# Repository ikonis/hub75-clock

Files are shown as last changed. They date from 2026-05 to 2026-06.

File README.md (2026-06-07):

# HUB75 Smart Clock

I built this as a bedside clock and it got out of hand. It's a 64×32 HUB75 LED matrix running on a Raspberry Pi 4, showing the time and animated weather conditions pulled from Home Assistant. The LD2410C mmWave sensor handles presence detection, a VEML7700 reads ambient light, and a PIR catches motion. Everything talks to HA over MQTT and shows up as a native device with auto-discovered entities.
Configuration is all YAML. Fonts, colors, brightness curves, which sensors are connected.

Parts of this codebase were written with AI assistance. I have tested it on my own hardware but please audit the code before running it on yours.

---

## Hardware

| Component | Notes |
|---|---|
| [Raspberry Pi 4 Model B](https://amzn.to/4nli8DE) | Debian Bookworm (Raspberry Pi OS Lite), primary supported hardware |
| [64×32 HUB75 LED panel](https://amzn.to/4tELsqA) | P2.5 used in this build. P2/P3/P4/P5 all work electrically; smaller pitch looks better up close |
| [VEML7700](https://amzn.to/3R5NwKr) | Ambient lux, I²C |
| [HLK-LD2410C](https://amzn.to/3Rz9upi) | mmWave presence + distance, UART |
| [PIR sensor (Inland PIR Motion Sensor Module)](https://www.microcenter.com/product/618776/inland-pir-motion-sensor-module) | Motion, GPIO, no adjustment pots, 3-pin VCC/GND/OUT |
| [5V / 5A power supply](https://amzn.to/4drKXKq) | Barrel jack, powers panel + Pi + sensors |

---

## Case / Enclosure

STL and STEP files are in the `case/` folder, designed for the hardware listed in the BOM above. A Bambu Studio `.3mf` file with the print settings used on a P1S is included.

### Variants

**Front cover**
- With cutouts for all three sensors (VEML7700 lux window, PIR dome, LD2410C lens)
- Without VEML7700 cutout, for builds that omit the lux sensor

**Back cover**
- Barrel jack only
- Pi 4 variant with and full port rear cutouts.

**Bottom cover**
- Pi 4
- Pi Zero W

### Hardware required

| Qty | Part | Notes |
|-----|---|---|
| 10 | [M3×5×4 Heatset Inserts](https://amzn.to/3RABtF4) | Panel and cover mounting |
| 6 | [M3×6 Countersunk Screws](https://amzn.to/4wqe6Or) | Front cover to frame |
| 6 | [M3×6 Hex Screws](https://amzn.to/3R4CC7Q) | Back cover to frame |
| 4 | [M2.5×3.5×4 Heatset Inserts](https://amzn.to/3RABtF4) | Pi mounting |
| 4 | [M2.5×5 Hex Screws](https://amzn.to/4u9nSTS) | Pi to standoffs |

---

## Wiring

### Power

```
5V/5A Supply (+) -----> Panel 5V
5V/5A Supply (+) -----> Pi VBUS (physical pin 2)
5V/5A Supply (+) -----> LD2410C VCC
5V/5A Supply (+) -----> PIR VCC
5V/5A Supply (-) -----> Shared GND (all devices)
```

Internal to the enclosure: barrel jack in, split to panel and Pi. One cable in, everything powered.

### VEML7700, I2C, 3.3V

```
VEML7700    Pi 4                Physical pin
VIN    -->  3.3V                1
GND    -->  GND                 9
SDA    -->  GPIO2 (SDA1)        3
SCL    -->  GPIO3 (SCL1)        5
```

Verify after boot: `sudo i2cdetect -y 1`. Expect `0x10`.

### HLK-LD2410C, UART, 5V power

```
LD2410C     Pi 4                Physical pin
VCC    -->  5V                  2
GND    -->  GND                 20
TX     -->  GPIO15 (RXD0)       10   ← CROSSED: sensor TX to Pi RX
RX     -->  GPIO14 (TXD0)       8    ← CROSSED: sensor RX to Pi TX
OUT         (leave unconnected)
```

After install + reboot: `ls -l /dev/ttyAMA0` must exist and `/dev/serial0` must point to it, not `ttyS0`. If it shows `ttyS0` the Bluetooth disable didn't take. Check `/boot/firmware/config.txt` for `dtoverlay=disable-bt`.

### PIR, GPIO

| PIR Pin | Pi BCM GPIO | Pi Physical Pin |
|---|---|---|
| VCC | 3.3V or 5V | Pin 1 or Pin 2 |
| GND | GND | Pin 39 |
| OUT | GPIO16 | Pin 36 |

> GPIO16 is free in the regular hardware mapping. OE uses GPIO18, not GPIO16.

> The Inland PIR sensor works on 3.3V, freeing up the 5V pins for panel power. If powering the Pi from a barrel jack via GPIO rather than USB-C, connect PIR VCC to pin 1 (3.3V) instead.

Change GPIO pin in `config.yaml` under `sensors.pir_gpio` (BCM number, not physical pin). Allow 30–60 seconds warmup after power-on.

### HUB75 Panel

Connect directly via GPIO, no HAT required. Panel power comes from the external supply directly, not through the Pi's 5V rail.

| HUB75 Signal | HUB75 IDC Pin | Pi BCM GPIO | Pi Physical Pin |
|---|---|---|---|
| R1 | 1 | GPIO11 | 23 |
| G1 | 2 | GPIO27 | 13 |
| B1 | 3 | GPIO7 | 26 |
| GND | 4 | GND | 6 |
| R2 | 5 | GPIO8 | 24 |
| G2 | 6 | GPIO9 | 21 |
| B2 | 7 | GPIO10 | 19 |
| GND | 8 | GND | 14 |
| A | 9 | GPIO22 | 15 |
| B | 10 | GPIO23 | 16 |
| C | 11 | GPIO24 | 18 |
| D | 12 | GPIO25 | 22 |
| CLK | 13 | GPIO17 | 11 |
| STB/LAT | 14 | GPIO4 | 7 |
| OE | 15 | GPIO18 | 12 |
| GND | 16 | GND | 25 |

> **Note:** This is the `regular` hardware mapping from rpi-rgb-led-matrix. Your HUB75 panel connector pin numbering may differ. Verify against your panel's datasheet. Pin 1 is usually marked on the connector.

> Pin 1 on the IDC connector is usually marked with a triangle or dot on the PCB silkscreen, or a red stripe on the ribbon cable.

**Note on 3.3V logic:** The Pi's GPIO is 3.3V. HUB75 panels expect 5V logic. Most panels tolerate 3.3V and work fine. If you get garbled output that `gpio_slowdown` tuning doesn't fix, a 74HCT245 buffer between Pi and panel will resolve it.

Use `hardware_mapping: regular` for direct GPIO wiring. Only use `adafruit-hat` if you have an actual Adafruit RGB Matrix Bonnet.

---

## Installation

> **Note:** Git may not be installed on a fresh Raspberry Pi OS image. Install it first:
> ```bash
> sudo apt install -y git
> ```

### 1. Clone the repo on the Pi

```bash
cd ~
git clone https://github.com/YOUR_GITHUB_USER/hub75-clock.git
cd hub75-clock
```

### 2. Install

```bash
bash install.sh
```

`install.sh` handles everything in one step, asks which runtime to install, then launches the interactive configuration wizard (`scripts/configure.sh`) and prompts to reboot. The Python runtime is the stable/public path. The C++ runtime is available as **experimental** for lower overhead, but fresh installs still need more testing.

### 3. Reboot

Prompted automatically by `install.sh`. Required for UART, Bluetooth, and group changes to take effect.

```bash
sudo reboot
```

### 4. Test sensors

```bash
make test
```

Runs each enabled sensor in sequence with a timed window and prints a PASS/FAIL/SKIP summary. Takes ~25 seconds total. Wave your hand in front of the PIR during the last 15 seconds.

```bash
sudo i2cdetect -y 1        # VEML7700 at 0x10
ls -l /dev/serial0         # must point to ttyAMA0
```

### 5. Test the clock

Python runtime:

```bash
sudo python3 /opt/hub75-clock/hub75_clock.py
```

C++ runtime:

```bash
sudo /opt/hub75-clock/hub75_clock /etc/hub75-clock/config.yaml
```

Root required for matrix DMA/PWM. Panel should light up with time. Banner shows `--/-- CLEAR` until HA pushes weather. The C++ runtime is **experimental** and may require dependency/build troubleshooting on fresh installs.

### 6. Start the service

The service is installed and enabled automatically by `install.sh`.

```bash
make start
make status
```

---

## Scripts

### install.sh

Run once on a fresh Pi. Does everything in sequence:

1. Updates apt package lists
2. Installs common system packages, then installs C++ build dependencies only when the C++ runtime is selected
3. Installs Python packages (paho-mqtt, PyYAML, pyserial, RPi.GPIO, adafruit-circuitpython-veml7700, adafruit-blinka, watchdog)
4. Lets you choose the clock runtime:
   - Python Clock: stable path, fast updates, no clock compile required
   - C++ Clock **[EXPERIMENTAL]**: lower overhead, smoother on constrained hardware, compiles during install/update
5. Lets you choose the theme builder mode: off, Home Assistant controlled, or always running
6. Builds and installs `rpi-rgb-led-matrix` with Python bindings. Pi 4: installs a pinned commit via pip. Pi Zero W: clones, checks out commit `076c54b`, and builds with `make build-python` / `make install-python`. The C++ runtime also builds the matrix C++ library. See `docs/pi-zero-w.md`.
7. Downloads fonts (rpi-rgb-led-matrix bundled BDF fonts + Spleen 12x24/16x32) to `~/hub75-fonts`
8. Enables I2C and UART hardware; disables serial console; disables Bluetooth; blacklists `snd_bcm2835`
9. Adds user to `dialout`, `gpio`, `i2c` groups
10. Installs the selected runtime to `/opt/hub75-clock/`; copies built-in themes to `/etc/hub75-clock/themes/` on first install only; update scripts preserve locally edited themes before syncing; copies Python animation `.py` files when using the Python runtime; installs the theme builder helper files
11. Installs and enables the `hub75-clock` systemd service for the selected runtime
12. Installs the `hub75-theme-builder` systemd service, enabled only when theme builder mode is `always`
13. Installs the matching update script to `~/update-clock.sh`
14. Launches `scripts/configure.sh` to write your `config.yaml`
15. Prompts to reboot

```bash
bash install.sh
```

### update scripts

Pulls the latest code from GitHub, copies updated files to `/opt/hub75-clock/`, and restarts the service. `install.sh` installs either `scripts/update-clock-python.sh` or `scripts/update-clock-cpp.sh` as `~/update-clock.sh`, matching the runtime you selected.

```bash
make update
# or: ~/update-clock.sh
```

For C++ clocks, `make update` rebuilds the C++ binary after syncing themes, sprites, and sprite-animation JSON. Normal theme/sprite JSON edits do not require a rebuild by themselves; the C++ clock reloads theme JSON changes while running. New C++ animation code or changes under `clock-cpp/src/animations/` require `make update`. Treat this runtime as **experimental** until the install path has been tested on more fresh Pi images.

The C++ updater checks for build dependencies before compiling. If a migrated clock is missing them, install:

```bash
sudo apt install -y cmake build-essential pkg-config libmosquitto-dev libyaml-cpp-dev libgpiod-dev
```

It also expects the RGB matrix source and C++ library at `~/rpi-rgb-led-matrix`:

```bash
cd ~
git clone https://github.com/hzeller/rpi-rgb-led-matrix.git
cd rpi-rgb-led-matrix
make
```

### switching runtimes

The installed runtime is controlled by the `hub75-clock` systemd service and the updater copied to `~/update-clock.sh`.

To switch from Python to C++ **[EXPERIMENTAL]**:

```bash
cp ~/hub75-clock/scripts/update-clock-cpp.sh ~/update-clock.sh
chmod +x ~/update-clock.sh
make update
sudo systemctl edit --full hub75-clock
```

Set `ExecStart` to:

```ini
ExecStart=/opt/hub75-clock/hub75_clock /etc/hub75-clock/config.yaml
```

Then:

```bash
sudo systemctl daemon-reload
sudo systemctl restart hub75-clock
```

To roll back to Python:

```bash
cp ~/hub75-clock/scripts/update-clock-python.sh ~/update-clock.sh
chmod +x ~/update-clock.sh
make update
sudo systemctl edit --full hub75-clock
```

Set `ExecStart` to:

```ini
ExecStart=/usr/bin/python3 /opt/hub75-clock/hub75_clock.py
```

Then reload and restart systemd again.

### scripts/configure.sh

Interactive configuration wizard. Prompts for your MQTT broker, device name, sensor hardware, GPIO pin, and `gpio_slowdown`, then writes `/etc/hub75-clock/config.yaml` automatically. Launched by `install.sh` on first install; can be re-run any time.

```bash
make config
# or: bash scripts/configure.sh
```

### clock/test_sensors.py

Tests each connected sensor independently without starting the full clock. Reads enabled flags from `config.yaml`, skips disabled sensors, and prints a PASS/FAIL/SKIP summary. Takes ~25 seconds total.

```bash
make test
```

---

## Daily Workflow

```bash
make update     # git pull + copy files + restart service
make logs       # tail live service logs
make restart    # restart after config edit
make status     # check service status
make stop       # stop the service
make start      # start the service
make test       # run test_sensors.py
make config     # open config wizard (reconfigure)
make rgb        # run test_display.py (panel pixel test)
make theme-builder # edit repo themes in the browser
make sprite-builder # edit sprite JSON files in the browser
make ld2410-tuner # tune LD2410 gate thresholds from a phone-friendly page
```

After editing `/etc/hub75-clock/config.yaml` directly:
```bash
make restart
```

---

## Theme Builder

The offline builder is `tools/theme-builder.html`. To edit theme JSON files directly through the browser, run the tiny local helper server:

```bash
make theme-builder
# open http://127.0.0.1:8765/
```

By default it reads and saves themes in the repo `themes/` directory. To edit the installed themes on a clock:

```bash
sudo python3 tools/theme-server.py --themes-dir /etc/hub75-clock/themes --host 0.0.0.0
```

Then browse to `http://<clock-ip>:8765/`. Only run it on a trusted network.

During install, the theme builder can be disabled, left always running, or controlled from Home Assistant. In HA-controlled mode, the clock publishes a Theme Builder switch and a Theme Builder URL sensor through MQTT discovery. The switch starts/stops the `hub75-theme-builder` service; the URL sensor gives you the browser address.

---

## LD2410 Tuner

The LD2410 tuner is a tiny mobile-friendly web UI for live gate tuning:

```bash
make ld2410-tuner
# open http://<clock-ip>:8766/
```

It uses MQTT instead of opening the UART directly, so the clock can keep running while the tuner turns engineering mode on, reads the sensor's saved thresholds, graphs live move/still gate energy, and publishes gate threshold changes through the same commands the clock already understands. Set `ld2410_tuner.mode` to `ha` to expose an HA switch and URL sensor, or `always` to keep the tuner service running.

Distances in the tuner are shown in feet. The LD2410 stores normal gate sensitivity after successful configuration commands. The next tuning layer can expose max-distance, timeout, and distance-resolution controls; distance resolution requires a module restart before it truly takes effect.

---

## Sprite Builder

The sprite builder edits small JSON sprites used by the generic `sprite` cameo in both runtimes:

```bash
make sprite-builder
# open http://127.0.0.1:8765/sprite-builder.html
```

Sprites live in `sprites/` in the repo and `/etc/hub75-clock/sprites/` on clocks. The same page also includes early animation scaffolding for frame-based sprite animation JSON in `sprite-animations/` and `/etc/hub75-clock/sprite-animations/`.

Use sprites from a theme cameo like:

```json
{ "name": "sprite", "sprite": "rocket", "chance_per_minute": 4 }
```

Sprite pixels use `null` for transparent cells, `#RRGGBB` for solid color, or `#RRGGBBAA` for alpha-blended pixels. Sprite JSON can also carry early `movement` metadata for future cameo behavior work. The sprite animation and cameo designer UI is scaffold/experimental design tooling; generated movement JSON is not yet a complete public runtime system.

---

## Updating

Pull the latest code from GitHub and restart the service:

```bash
make update
# or: ~/update-clock.sh
```

This pulls from the current branch, copies the updated files to `/opt/hub75-clock/`, and restarts the service. On the C++ runtime it also rebuilds the binary; on Python it copies the `.py` files directly.

---

## Font Selection

Two fonts configured separately: banner (small text row) and time (large digits).

### Banner font

`4x6.bdf` (default): "TSTORM" plus two temps fits in 64px.

### Time font options

| Font | W×H | "12:34" px wide | Source | Notes |
|---|---|---|---|---|
| `9x15B.bdf` | 9×15 | 45px | rpi-rgb-led-matrix | Smaller bold |
| `9x18B.bdf` | 9×18 | 45px | rpi-rgb-led-matrix | Taller bold |
| `10x20.bdf` | 10×20 | 50px | rpi-rgb-led-matrix | Good default |
| `spleen-12x24.bdf` | 12×24 | 60px | install.sh | Chunky terminal. Recommended upgrade. |
| `spleen-16x32.bdf` | 16×32 | 80px | install.sh | Extreme chonk. Single-digit hours only ("6:15"=48px ✓, "12:34"=80px ✗) |

To change the time font, edit `/etc/hub75-clock/config.yaml`:

```yaml
fonts:
  time_name: spleen-12x24.bdf
  time_w: 12
  time_h: 24
```

**Always update `time_w` and `time_h`. They are not auto-detected.**

Browse available fonts:
```bash
ls ~/rpi-rgb-led-matrix/fonts/
```

Test a font on the real panel:
```bash
cd ~/rpi-rgb-led-matrix/examples-api-use
sudo ./text-example -f ~/rpi-rgb-led-matrix/fonts/spleen-12x24.bdf
```

---

## Home Assistant Setup

### Optional Home Assistant Automation Examples

The clock does not require my Home Assistant helpers, room names, weather entities, or automation structure. It only needs MQTT. You can publish to the topics in `config.yaml` from HA, Node-RED, a shell script, or nothing at all. Without weather MQTT, the clock still runs and shows placeholder banner values until something publishes weather.

The files in `automations/` are optional examples. Copy them only if you want a starting point, then replace the placeholder entity IDs (`YOUR_CLOCK_CLIENT_ID`, `weather.YOUR_WEATHER_ENTITY`, etc.) with your own.

```text
config/
|-- packages/
|   `-- hub75_clock/
|       |-- 01_set_theme.yaml            optional: brightness + calls theme script
|       |-- 01b_select_theme_script.yaml SCRIPT (see note below)
|       |-- 02_push_weather.yaml         optional: weather push every 15 min
|       |-- 03_alerts.yaml               optional: NWS weather alert banner
|       `-- 04_online_offline.yaml       optional: offline notification
`-- scripts/
    `-- clocks_select_theme.yaml         copy of 01b content under script: key
```

In `configuration.yaml`:

```yaml
homeassistant:
  packages: !include_dir_named packages

script: !include_dir_merge_named scripts
```

**Important:** `01b_select_theme_script.yaml` is a script, not an automation. It defines `script.clocks_select_theme`, which the optional `01_set_theme.yaml` automation calls. Scripts and automations use different HA keys and cannot live in the same file. Copy the contents of `01b_select_theme_script.yaml` into your `config/scripts/` directory, or inline it under a `script:` key in a package.

Optional helpers used by the examples:

| Helper | Type | Used for |
|---|---|---|
| `input_select.clock_daypart` | Select | Optional day/night/Away theme selection. Suggested values: Day, Early Morning, Evening, Late Evening, Night, Away. |
| `input_text.clock_condition` | Text | Optional weather condition cache. Written by `02_push_weather`, read by `01b_select_theme_script`. |

Optional entities used by the examples:

| Entity | Source |
|---|---|
| `weather.YOUR_WEATHER_ENTITY` | Any HA weather integration |
| `sensor.YOUR_OUTDOOR_TEMP` | Optional outdoor/current temperature sensor |
| `number.YOUR_CLOCK_CLIENT_ID_brightness` | Auto-discovered brightness control |
| `binary_sensor.YOUR_CLOCK_CLIENT_ID_online` | Auto-discovered availability sensor |

These names are examples, not requirements. If you already have different helpers or entities, map them in the automation YAML or publish directly to MQTT.

### Auto-registered entities (MQTT Discovery)

The clock registers its device and all entities automatically via MQTT Discovery on connect. The device name and entity prefix come from `mqtt.client_id` and `ha_discovery.ha_discovery_name` in `config.yaml`.

With defaults (`client_id: hub75_clock`, `ha_discovery_name: "HUB75 Clock"`):

| Entity | Description |
|---|---|
| `sensor.hub75_clock_illuminance` | VEML7700 lux |
| `sensor.hub75_clock_move_distance` | LD2410C move distance (cm) |
| `sensor.hub75_clock_still_distance` | LD2410C still distance (cm) |
| `binary_sensor.hub75_clock_pir` | PIR motion (shown as "Motion" in HA) |
| `binary_sensor.hub75_clock_presence` | LD2410C occupancy |
| `number.hub75_clock_brightness` | Brightness control (1–100) |

Sensors for disabled hardware (e.g. `veml7700_enabled: false`) are not registered. LD2410 gate energy, gate thresholds, and engineering mode are intentionally kept out of Home Assistant; use the LD2410 tuner web UI or RadarTools for tuning.

### MQTT Topics

**HA → Clock:**

| Topic | Payload |
|---|---|
| `clock/weather` | `{"low_temp": 68, "high_temp": 88, "condition": "TSTORM", "outdoor_temp": 64}` |
| `clock/config` | `{"brightness": 40}` — brightness; additional config keys documented in `config.example.yaml` |
| `{client_id}/theme/set` | Theme name string, e.g. `"Rainy Night"` — per-clock, uses `mqtt.client_id` from config |
| `clock/alert` | `{"message": "Tornado Warning - County - until 4:45 PM", "expires": "2026-04-25T16:45:00-05:00"}` |
| `clock/alert` | `{"clear": true}` to dismiss |

Minimal generic HA service calls:

```yaml
# Set one clock's theme manually.
action: mqtt.publish
data:
  topic: hub75_clock/theme/set
  payload: "Night - Clear"
```

```yaml
# Publish weather/banner data.
action: mqtt.publish
data:
  topic: clock/weather
  retain: true
  payload: '{"low_temp": 68, "high_temp": 88, "condition": "CLEAR", "outdoor_temp": 72}'
```

```yaml
# Publish brightness. If several clocks share clock/config, they all change.
action: mqtt.publish
data:
  topic: clock/config
  payload: '{"brightness": 40}'
```

```yaml
# Optional day/night theme selection idea.
action: mqtt.publish
data:
  topic: hub75_clock/theme/set
  payload: >
    {% if is_state('sun.sun', 'below_horizon') %}
      Night - Clear
    {% else %}
      Day - Clear
    {% endif %}
```

**Clock → HA:**

| Topic | Payload |
|---|---|
| `hub75_clock/lux` | `{"lux": 125.5}` |
| `hub75_clock/pir` | `{"motion": true}` |
| `hub75_clock/presence` | `{"presence": true, "target_state": 3, "move_distance": 85, "still_distance": 120}` |
| `hub75_clock/motion` | `{"move_energy": 45, "still_energy": 30}` |
| `hub75_clock/status` | `online` or `offline` |

### Weather Conditions

If you publish weather data, the clock expects a condition string. The optional example script `clocks_select_theme` maps condition + daypart to a matching theme name, but you can use any mapping you like or select themes manually.

| Condition | Day-side theme | Night-side theme |
|---|---|---|
| `CLEAR` / `SUNNY` / `PARTLYCLOUDY` | Day / Sunrise / Sunset | Night / Late Evening |
| `CLOUDY` / `FOG` / `SMOKE` / `DUST` / `WINDY` | Day (overcast sky) | Night (no stars) |
| `RAIN` / `FLOOD` | Rainy Day | Rainy Night |
| `TSTORM` / `HURRICANE` / `TROPICAL_STORM` | Stormy Day | Stormy Night |
| `SNOW` / `BLIZZARD` | Snowy Day | Snowy Night |
| `SLEET` / `ICE` / `FREEZING_DRIZZLE` / `FREEZING_RAIN` | Sleety Day | Rainy Night |

All precipitation (rain drops, snow flakes, sleet, lightning) is rendered by the `clouds.py` animation via the `precipitation` field in the theme JSON. See `docs/themes.md` for the full field reference.

In the included `02_push_weather.yaml` example, condition is the most severe expected in the next 12 hours, not just the current moment.

The condition and temperature windows are configurable at the top of `automations/02_push_weather.yaml`. Change `condition_hours` (default 12) and `temp_hours` (default 24) to suit your preference.

### Brightness

Brightness can be controlled from the auto-discovered HA number entity or by publishing `{"brightness": 40}` to the configured config topic. The included `automations/01_set_theme.yaml` file is only one optional example.

---

## Tornado Warning Alert

When a Tornado Warning is issued, the banner strip shows a red scrolling overlay. Time and animations stay below. Auto-clears on expiration.

### NWS Alerts setup (HACS)

1. HACS → Integrations → ⋮ → Custom Repositories
2. Add: `https://github.com/finity69x2/nws_alerts` → Integration
3. Install "NWS Alerts" → Restart HA
4. Settings → Devices & Services → Add Integration → NWS Alerts
5. Configure with your GPS coordinates or county code

Only Tornado Warnings trigger the clock alert by default.

To manually test the alert:
```bash
mosquitto_pub -h <broker> -u <user> -P <pass> \
  -t clock/alert \
  -m '{"message":"TEST - County - until 11:59 PM"}'
```

Clear it:
```bash
mosquitto_pub -h <broker> -u <user> -P <pass> \
  -t clock/alert -r \
  -m '{"clear": true}'
```

---

## Troubleshooting

**Blank panel:** Check 5V supply. Check ribbon cable orientation (input side of panel only).

**Garbled colors:** Adjust `panel.gpio_slowdown` (Pi 4: start at 4, try 3–5). If still wrong, add a 74HCT245 buffer.

**Flickering:** Increase `gpio_slowdown`. Confirm `lsmod | grep snd_bcm2835` returns nothing. Service must run as root.

**Time wrong size/position:** `fonts.time_w` and `fonts.time_h` must match the font file exactly. Not auto-detected.

**`/dev/serial0` is `ttyS0`:** Bluetooth still owns PL011. Check for `dtoverlay=disable-bt` in `/boot/firmware/config.txt`. Add it and reboot.

**VEML7700 not found:** `sudo i2cdetect -y 1` should show `10`. Check wiring. Set `sensors.veml7700_enabled: false` to disable.

**Weather stuck at `--/-- CLEAR`:** Manually trigger the weather push automation in HA Developer Tools → Automations. Check the automation trace.

**Alert not clearing:** Publish `{"clear": true}` to `clock/alert` from HA Developer Tools → MQTT.

**`mqtt.broker is not set` error on startup:** Add your broker IP to `/etc/hub75-clock/config.yaml` under `mqtt.broker`, or run `make config` to reconfigure.

---

## File Layout

```
hub75-clock/
├── .gitignore
├── Makefile                    make update / logs / restart / test / config / rgb
├── README.md
├── config.example.yaml         Reference config; configure.sh writes the real config
├── install.sh                  One-shot installer, run once on a fresh Pi
├── update.sh                   Installed to ~/update-clock.sh; called by make update
├── scripts/
│   ├── configure.sh            Interactive config wizard; run by install.sh
│   └── test_display.py         Panel pixel test (make rgb)
├── clock/
│   ├── hub75_clock.py          Main application
│   ├── theme_loader.py         Theme dataclass, JSON loader, file watcher
│   └── test_sensors.py         Per-sensor test utility (make test)
├── themes/
│   └── *.json                  Built-in themes; locally edited installed themes are preserved by update scripts
├── animations/
│   └── *.py                    Built-in drop-in animations; copied to /etc/hub75-clock/animations/
│                               Drop your own .py files there to add custom animations at runtime
├── sprites/
│   └── *.json                  Sprite cameo art for the generic sprite animation
└── automations/
    ├── 01_set_theme.yaml            Optional brightness + theme selection example
    ├── 01b_select_theme_script.yaml Optional script: maps daypart + condition to a theme
    ├── 02_push_weather.yaml         Optional forecast weather MQTT example
    ├── 03_alerts.yaml               NWS alert banner (shared clock/alert topic, all clocks receive)
    └── 04_online_offline.yaml       Optional offline notification example
```

Python custom animations can be added at runtime by dropping a `.py` file into `/etc/hub75-clock/animations/`. C++ animation code lives under `clock-cpp/src/animations/` and is compiled during `make update`. Theme JSON, sprite JSON, and sprite-animation JSON edits do not require a C++ recompile. See `docs/animations.md` for the full interface.

---

## Other Hardware

The Pi 4 is the primary tested platform. Other hardware may work with adjustments:

**Raspberry Pi Zero W**: requires additional build steps. See `docs/pi-zero-w.md`.

**Raspberry Pi 3B / 3B+**: should work with `gpio_slowdown: 3` in `config.yaml`. Untested.

**Raspberry Pi 5**: not currently supported.

---

## Compatibility

| Hardware | Status |
|---|---|
| Raspberry Pi 4 Model B | ✅ Primary / tested |
| Raspberry Pi Zero W 1.1 | 🔧 Community-supported; see `docs/pi-zero-w.md` |
| Raspberry Pi 3B / 3B+ | 🔧 Community-supported, untested, `gpio_slowdown: 3` |
| Raspberry Pi 5 | ❌ Not supported |

---

## Support

---

## License

MIT.

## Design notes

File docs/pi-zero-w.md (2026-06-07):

# HUB75 Smart Clock: Raspberry Pi Zero W Build Notes

> **Note:** The Raspberry Pi 4 is the primary supported platform. This document covers the additional steps required to build and run the clock on a Pi Zero W. These steps are community-supported and require more technical comfort.

---

## Why Pi Zero W Needs Extra Steps

The Pi Zero W uses an ARMv6 processor. Recent versions of the `rpi-rgb-led-matrix` library include code for the Raspberry Pi 5's RP1 chip which fails to compile on ARMv6. `install.sh` works around this by pinning to commit `076c54b`, the last version before RP1 support was added, and building with the library's own `make build-python` target instead of pip.

---

## Hardware Differences

| | Pi Zero W | Pi 4 |
|--|--|--|
| Architecture | ARMv6 32-bit | ARMv8 64-bit |
| gpio_slowdown | 2 | 4 |
| UART port | /dev/serial0 | /dev/ttyAMA0 |
| Performance | Slower, some lag on config changes | Fast, very responsive |
| Build process | Requires RP1 stub hack | Standard build |

---

## OS

Use **Raspberry Pi OS Lite (32-bit, Bookworm)**. Do NOT use 64-bit on Pi Zero W. It is not supported on ARMv6.

---

## Building rpi-rgb-led-matrix on Pi Zero W

`install.sh` handles this automatically. It detects Pi Zero W at runtime, then:

1. Clones `rpi-rgb-led-matrix` to `~/rpi-rgb-led-matrix`
2. Checks out commit `076c54b` (last version before Pi 5 RP1 support was added; later commits fail to compile on ARMv6)
3. Builds the C++ library and Python bindings with the repo's own build targets:

```bash
make build-python PYTHON="$(which python3)"
sudo make install-python PYTHON="$(which python3)"
```

Just run `bash install.sh` as normal. No manual source edits are needed.

If a clock is migrated to the C++ runtime after an older Python-only install, make sure the C++ build dependencies are present:

```bash
sudo apt install -y cmake build-essential pkg-config libmosquitto-dev libyaml-cpp-dev libgpiod-dev
```

The C++ updater also expects the RGB matrix source tree and static library at `~/rpi-rgb-led-matrix`. If they are missing:

```bash
cd ~
git clone https://github.com/hzeller/rpi-rgb-led-matrix.git
cd rpi-rgb-led-matrix
make
```

Normal theme JSON edits do not require a C++ recompile. New C++ animation code or edits under `clock-cpp/src/animations/` do require `make update`.

### Verify after install

```bash
python3 -c "from rgbmatrix import RGBMatrix, RGBMatrixOptions, graphics; print('OK')"
```

---

## Config Changes for Pi Zero W

In `/etc/hub75-clock/config.yaml`:

```yaml
panel:
  gpio_slowdown: 2  # Pi Zero W value

sensors:
  ld2410_port: /dev/serial0  # Pi Zero W UART
```

---

## Performance Notes

The Pi Zero W is a single-core ARMv6 at 1GHz. The installer defaults to the C++ runtime on Pi Zero because it has the lowest CPU overhead, but the Python runtime remains available if you want it. Both runtimes now default to 90fps.

Things that can still add load:

- Receiving lots of MQTT messages (gate data, engineering mode)
- Changing weather condition or theme inputs rapidly

For best performance on Zero W:
- Keep `engineering_mode` off unless actively tuning
- Use the C++ runtime if the Python runtime feels sluggish
- Set `sensors.lux_interval: 60` (already default)

---

## UART on Pi Zero W

Enable UART the same way as Pi 4 via `raspi-config`. The port will be `/dev/serial0` which is a symlink to the correct UART device.

If you have Bluetooth issues (Zero W has BT on the main UART), disable it:

```bash
sudo systemctl disable hciuart
```

Add to `/boot/firmware/config.txt`:
```
dtoverlay=disable-bt
enable_uart=1
```

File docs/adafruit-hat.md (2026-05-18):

# HUB75 Smart Clock: Adafruit RGB Matrix HAT

> **Note:** HAT support is untested and community-supported. The primary supported build uses direct GPIO wiring without a HAT. These notes are provided for users who already have an Adafruit HAT and want to try it, but issues specific to the HAT configuration are not actively supported.

Using an Adafruit RGB Matrix HAT simplifies wiring significantly. Just plug the HAT onto the Pi's 40-pin header and connect the HUB75 panel to the HAT's output connector.

---

## Compatible HATs

| HAT | Notes |
|-----|---|
| [Adafruit RGB Matrix HAT + RTC](https://www.adafruit.com/product/2345) | Basic HAT, no PWM mod |
| [Adafruit RGB Matrix Bonnet](https://www.adafruit.com/product/3211) | Smaller form factor, same pinout |

Both include built-in level shifters, so no separate level shifting is needed.

---

## Wiring

Simply:
1. Seat the HAT onto the Pi 40-pin GPIO header
2. Connect the HUB75 panel's data cable to the HAT's HUB75 output connector
3. Connect panel power (5V) to the HAT's power input terminals or directly to the panel

That's it. No individual wire connections needed.

---

## Config Changes

In `/etc/hub75-clock/config.yaml`, change `hardware_mapping`:

**Standard HAT (no PWM mod):**
```yaml
panel:
  hardware_mapping: adafruit-hat
  gpio_slowdown: 4  # Pi 4
```

**HAT with PWM modification (better image quality, less flicker):**
```yaml
panel:
  hardware_mapping: adafruit-hat-pwm
  gpio_slowdown: 4  # Pi 4
```

---

## PWM Modification (Optional but Recommended)

The Adafruit HAT has a solder jumper that enables hardware PWM for smoother display output. See Adafruit's guide:
https://learn.adafruit.com/adafruit-rgb-matrix-plus-real-time-clock-hat-for-raspberry-pi/driving-matrices

If you do the PWM mod, use `adafruit-hat-pwm` as the hardware_mapping.

---

## Sensor Wiring with HAT

The HAT occupies most of the GPIO header but leaves some pins exposed. Check your specific HAT's documentation for which pins are available.

For the LD2410C UART, the HAT typically leaves the UART pins (GPIO14/15, physical pins 8/10) accessible. Connect LD2410C to those.

For the PIR sensor, use a GPIO pin that is not used by the HAT. GPIO26 (physical pin 37) is typically free on Adafruit HATs.

---

## configure.sh

When running `./scripts/configure.sh`, select **Adafruit HAT** or **Adafruit HAT (PWM mod)** when prompted for hardware mapping. The script will set the correct value automatically.

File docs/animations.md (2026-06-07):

# Animations

The C++ runtime uses the same cameo names as the Python runtime, but animation code is compiled from `clock-cpp/src/animations/*.cpp`. Adding or changing C++ animation code requires `make update` on the clock so the binary is rebuilt and reinstalled. Plain theme JSON, sprite JSON, and sprite-animation JSON edits do not require a C++ rebuild.

The Python runtime supports a drop-in animation system. Any `.py` file placed in `/etc/hub75-clock/animations/` is automatically loaded at runtime. The watchdog detects new and changed files within seconds — no restart required.

Animations are triggered as **cameos** inside theme JSON files. See `docs/themes.md` for how to add them to a theme.

---

## How the drop-in system works

1. `AnimationLoader` scans `/etc/hub75-clock/animations/` at startup and imports every `.py` file that contains a class named `Animation`.
2. Each `Animation` class is registered under its `name` attribute.
3. A watchdog monitors the directory. When any `.py` file changes or a new one appears, the loader rescans and rebuilds the registry.
4. The built-in `shooting_star` animation is always registered as a fallback even if the directory is empty.
5. `CameoManager` uses the registry when a theme's `cameos` list asks for an animation by name.

---

## Writing a custom animation

Create a file in `/etc/hub75-clock/animations/` with exactly this structure:

```python
import math
import random

class Animation:
    name = "my_animation"          # unique string key — must match what you put in themes
    conditions = []                # informational: intended weather conditions (not enforced at runtime)
    themes = []                    # informational: intended theme names (not enforced at runtime)
    layer = "foreground"           # "celestial" draws before sun/moon; "foreground" draws last
    persistent = False             # True = runs every frame without a chance_per_minute roll
    speed = 1.0                    # optional multiplier for motion/twinkle speed

    def __init__(self, width, height, cfg, animator):
        self._w = width
        self._at = animator.anim_top   # first row of the animation zone (row 8 on a 64×32 panel)
        self._ab = animator.anim_bottom  # last row of the animation zone (row 31)
        # Initialize your animation state here

    def update(self):
        # Advance state by one frame. Called every frame before draw().
        pass

    def draw(self, canvas):
        # Draw to canvas using canvas.SetPixel(x, y, r, g, b).
        # x must be in 0 .. width-1.
        # y must be in anim_top .. anim_bottom.
        # Do NOT draw outside the animation zone.
        pass

    def is_done(self) -> bool:
        # Return True when the animation has finished. CameoManager will discard it.
        # For persistent animations, return False always.
        return False
```

For Python, drop the file into `/etc/hub75-clock/animations/`. The clock picks it up within a few seconds. Add its `name` to a theme's `cameos` list:

```json
"cameos": [
  {"name": "my_animation", "chance_per_minute": 3}
]
```

---

## Cameo runtime

`CameoManager` maintains one one-shot animation slot plus persistent animations:

- **One-shot slot (`_active`)**: The normal cameo slot. Spawned via `chance_per_minute` probability rolls. Only one runs at a time; while one is active, new rolls are skipped. Cleared on condition change.
- **Persistent animations**: Started once when the theme is applied. They run every frame without any roll and are cleared only on theme change, surviving condition changes. Used for continuously visible effects such as `stars` and `clouds`.

A persistent animation sets `persistent = True` on its class and should return `False` from `is_done()` always. It does not need a `chance_per_minute` entry in the cameos array:

```json
"cameos": [{"name": "stars"}, {"name": "clouds"}]
```

---

## Draw layer ordering

Animations declare their draw layer via the `layer` class attribute:

| Value | When drawn | Examples |
|---|---|---|
| `"celestial"` | After background fill, before sun/moon and clouds | `stars`, `shooting_star`, `meteor`, `comet`, `satellite` |
| `"foreground"` | After clouds, on top of weather particles | `ghost`, `ufo`, all others |

Draw order each frame: background fill -> celestial cameos (`stars`, `shooting_star`, `meteor`, `comet`) -> sun/moon -> clouds and precipitation -> foreground cameos.

---

## Class attributes

### `name` (required)

A unique string key. This is what you put in the theme JSON. If two files declare the same name the second one loaded wins (load order is alphabetical by filename).

### `conditions` (optional, list of strings)

Informational metadata describing the weather conditions this animation is designed for (e.g. `["CLEAR", "RAIN"]`). **Not enforced at runtime.** The clock does not check this attribute before spawning — if the animation is listed in a theme's `cameos` array, it will fire regardless of the current weather condition.

Use this field as documentation for yourself and for tools like the theme builder. An empty list (`[]`) means "suitable for any condition."

### `themes` (optional, list of strings)

Informational metadata describing the theme names this animation is designed for (e.g. `["Night", "Day"]`). **Not enforced at runtime.** The clock does not check this attribute before spawning.

An empty list (`[]`) means "suitable for any theme."

### `layer` (optional, string)

Controls where in the draw stack this animation is rendered. Default is `"foreground"`.

- `"celestial"` — rendered after the background fill and before sun/moon and weather particles. Use for sky objects such as stars, meteors, shooting stars, satellites, and comets.
- `"foreground"` — rendered after clouds and precipitation. Use for everything else.

### `persistent` (optional, bool)

Default `False`. When `True`, the animation is instantiated once when the theme is applied and runs every frame without a `chance_per_minute` roll. It is replaced only when the theme changes. Persistent animations should always return `False` from `is_done()`.

### `speed` (optional, float)

Default `1.0`. Built-in animations use this as a simple multiplier for movement, twinkle, or drift speed so timing can be tuned without rewriting update logic.

Python and C++ load runtime speed settings from `/etc/hub75-clock/animations.yaml` when present. The update scripts install the example file only if it is missing, so local speed tuning survives `make update`.

---

## `__init__` parameters

| Parameter | Type | Description |
|---|---|---|
| `width` | int | Panel width in pixels (64 for a 64×32 panel) |
| `height` | int | Panel height in pixels (32 for a 64×32 panel) |
| `cfg` | dict | The full clock config dict. Access MQTT or other settings if needed. Usually not needed. |
| `animator` | WeatherAnimator | The running animator instance. Use `animator.anim_top` and `animator.anim_bottom` for the animation zone boundaries. |

---

## Drawing API

`canvas.SetPixel(x, y, r, g, b)` — set a single pixel.

- `x`: 0–63 (left to right)
- `y`: 0–31 (top to bottom)
- `r`, `g`, `b`: 0–255

The animation zone runs from `anim_top` (row 8) to `anim_bottom` (row 31). Rows 0–7 are the banner strip (time, temps, condition). Always guard your pixel writes:

```python
if 0 <= px < self._w and self._at <= py <= self._ab:
    canvas.SetPixel(px, py, r, g, b)
```

---

## Minimal working example

A single pixel that blinks yellow and drifts across the screen:

```python
import random

class Animation:
    name = "blink_dot"
    conditions = []
    themes = []

    def __init__(self, width, height, cfg, animator):
        self._w = width
        self._at = animator.anim_top
        self._ab = animator.anim_bottom
        self.x = 0.0
        self.y = float(self._at + random.randint(0, self._ab - self._at))
        self._frame = 0

    def update(self):
        self.x += 0.4
        self._frame += 1

    def draw(self, canvas):
        if self._frame % 8 < 4:   # blink: on for 4 frames, off for 4
            px, py = int(self.x), int(self.y)
            if 0 <= px < self._w and self._at <= py <= self._ab:
                canvas.SetPixel(px, py, 255, 220, 0)

    def is_done(self) -> bool:
        return self.x > self._w + 2
```

---

## Built-in animations reference

Python installs these to `/etc/hub75-clock/animations/`. C++ compiles the matching sources from `clock-cpp/src/animations/` during `make update`.

### Space / Night

Celestial animations are drawn before sun/moon and clouds so meteors appear to fall behind weather. Foreground night animations draw after clouds.

| File | Name | Conditions | Themes | Description |
|---|---|---|---|---|
| `stars.py` | `stars` | CLEAR, PARTLYCLOUDY | Night, Late Evening | **Persistent.** Twinkling star field. Add without `chance_per_minute`; rendered in the celestial layer before sun/moon. |
| `shooting_star.py` | `shooting_star` | CLEAR, PARTLYCLOUDY | Night, Late Evening | Fast diagonal streak with fading tail. Built-in fallback; always registered even if the file is missing. |
| `ufo.py` | `ufo` | CLEAR, PARTLYCLOUDY | Night, Late Evening | Saucer silhouette drifting across with cycling teal belly lights, glow trail, and occasional tractor beam abduction sequence. |
| `satellite.py` | `satellite` | CLEAR | Night | ISS-profile cross sprite, slow diagonal pass from top-right to bottom-left. |
| `meteor.py` | `meteor` | CLEAR | Night, Late Evening | Fast bidirectional diagonal (3.5–5 px/frame) with 6-frame orange/red history trail. |
| `comet.py` | `comet` | CLEAR | Night | Slow diagonal with 10–14px blue-white gradient tail, always drifts downward. |

### Day / Sky (layer: foreground)

| File | Name | Conditions | Themes | Description |
|---|---|---|---|---|
| `clouds.py` | `clouds` | _(any)_ | Day, Sunrise, Sunset, Late Evening | **Persistent.** Drifting clouds plus optional precipitation particles. Count, size, and speed driven by `cloud_density`/`cloud_speed`. Precipitation type set by `precipitation` field (`"none"`, `"rain"`, `"heavy_rain"`, `"tstorm"`, `"snow"`, `"sleet"`). Tstorm mode adds random lightning bolts and background flash. All particles are owned by their parent cloud and wrap with it. |
| `airplane.py` | `airplane` | _(any)_ | Day, Sunrise, Sunset | 8px fuselage + wings + windows, random left/right direction, mirrors sprite to face direction of travel. |
| `sprite.py` / `sprite.cpp` | `sprite` | _(any)_ | _(any)_ | Generic JSON sprite cameo. Loads art from `/etc/hub75-clock/sprites/`; use theme JSON such as `{ "name": "sprite", "sprite": "rocket", "chance_per_minute": 4 }`. |
| `bird_flock.py` | `bird_flock` | _(any)_ | Day | V-formation of 5–7 birds with alternating flap frames. |
| `butterfly.py` | `butterfly` | CLEAR | Day | Open/closed wing frames every 5 ticks, sine wave vertical drift, orange. |
| `flutterflies.py` | `flutterflies` | CLEAR | Day | **Persistent.** Small pastel butterfly group with gentle wandering motion. Add without `chance_per_minute`. |
| `hot_air_balloon.py` | `hot_air_balloon` | CLEAR, PARTLYCLOUDY | Day, Sunrise | 7×10px balloon with ROYGBIV stripes, drifts upward. |
| `tumbleweed.py` | `tumbleweed` | _(any)_ | Day | 5px circle with rotation transform, slight bounce via `|sin|×1.5`. |

### Weather (layer: foreground)

| File | Name | Conditions | Themes | Description |
|---|---|---|---|---|
| `rainbow.py` | `rainbow` | CLEAR, PARTLYCLOUDY | Day | ROYGBIV arc using radius math per band, 2px thick, fade in 15 / hold 45 / fade out 15 frames. |
| `firefly.py` | `firefly` | CLEAR | Night, Late Evening | 6–8 dots with independent sine-phase blink, slow random drift, yellow-green, 2px tall. |
| `snowman.py` | `snowman` | SNOW | _(any)_ | Pixel-art snowman lower-right corner, fade in 20 / hold 90 / fade out 20 frames, flickering eyes. |

### Holiday (layer: foreground)

| File | Name | Conditions | Themes | Description |
|---|---|---|---|---|
| `santa.py` | `santa` | _(any)_ | Night, Late Evening | 14px-wide sleigh + reindeer silhouette, right-to-left, sine wave altitude. |
| `fireworks.py` | `fireworks` | _(any)_ | _(any)_ | 1–3 rockets with staggered launches. Physics-based: gravity applied each frame, apex triggers explosion. 16–20 sparks per burst with velocity-based tails at 60%/30% brightness. |
| `jack_o_lantern.py` | `jack_o_lantern` | _(any)_ | Night, Late Evening | 9×7px orange pumpkin with triangle eyes, triangle nose, zigzag mouth. Lower-right corner, fade in/out. |
| `easter_egg.py` | `easter_egg` | _(any)_ | Day | 6×8px oval with 4-color stripe pattern, bounces left-to-right with slight vertical bob. |

### Fun (layer: foreground)

| File | Name | Conditions | Themes | Description |
|---|---|---|---|---|
| `rocket.py` | `rocket` | _(any)_ | _(any)_ | 3×7px rocket sprite, accelerates upward from a random X position, flame trail below, exits top. |
| `submarine.py` | `submarine` | _(any)_ | Day | Long hull + conning tower + periscope, slow left-to-right with slight sine wave. |
| `ghost.py` | `ghost` | _(any)_ | Night, Late Evening | Pac-Man ghost (7×8px): Blinky/Pinky/Inky/Clyde colors, directional pupils, scalloped bottom, sine float. |

---

## Chance per minute tuning

`chance_per_minute` controls how often a cameo spawns on average. The roll is evaluated every frame:

```
probability_per_frame = chance_per_minute / 60 / fps
```

At 90 fps with `chance_per_minute: 8`:

```
8 / 60 / 90 = 0.0015  →  ~1 spawn per 675 frames (~7.5 seconds)
```

At lower FPS, the per-frame probability is higher so the per-minute rate stays the same:

```
8 / 60 / 30 = 0.0044  →  still ~8 spawns per minute on average
```

Typical values:

| Rate | Feel |
|---|---|
| 1–2 | Rare, occasional surprise |
| 4–8 | Regular — visible but not constant |
| 15–20 | Frequent |
| 30+ | Near-continuous |

Only one cameo runs at a time. While one is active, rolls for all cameos are skipped. High rates shorten the idle time between cameos; a new one starts almost immediately after the previous finishes.

---

## Tips

- **Keep animations entirely within the animation zone.** The banner rows (0–7) must stay intact. Always guard pixel writes with the `anim_top` / `anim_bottom` check.
- **Do not import heavy libraries.** `math` and `random` are always available. Avoid anything that requires install-time dependencies.
- **Name collisions:** if your file's `Animation.name` matches an existing built-in, your file wins because `_scan()` processes files alphabetically and yours will likely run after the built-in. Prefix custom names to avoid accidental overrides (`"my_ufo"` instead of `"ufo"`).
- **Errors are logged, not crashed.** If your file has a syntax error or the `Animation` class is missing required attributes, the loader prints a warning and skips the file. The rest of the animations continue working.
- **Test Python interactively:** run the clock manually (`sudo python3 /opt/hub75-clock/hub75_clock.py`) and watch the logs with `make logs` while you drop files in. The watchdog reloads within 2 seconds of a file write.
- **Test C++ changes:** run `make update` on the C++ clock. The C++ updater syncs themes/sprites first, then rebuilds `clock-cpp` and swaps the installed binary. Plain theme JSON, sprite JSON, and sprite-animation JSON edits do not require a C++ rebuild.

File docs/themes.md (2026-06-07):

# Themes

Themes control the background, text colors, and animation behavior of the clock face. Each theme is a JSON file. The clock loads all `.json` files from its themes directory at startup and watches for changes. Drop a new file in and the clock picks it up within seconds, no restart required.

---

## Where themes live

Built-in themes are installed to `/etc/hub75-clock/themes/` by `install.sh`. That is also where the clock reads them from at runtime. Add your own `.json` files to the same directory.

```
/etc/hub75-clock/themes/
├── Day - Clear.json
├── Day - Rain.json
├── Evening - Clear.json
├── Night - Partly Cloudy.json
├── Away.json
├── Test - shooting_star.json
└── your_custom_theme.json   ← drop it here
```

The repo ships the built-in themes under `themes/` and the installer copies them on first install. `make update` preserves installed themes by copying `/etc/hub75-clock/themes/` back into the repo before syncing, then commits and pushes theme changes by default. Set `PRESERVE_LOCAL_THEMES=false`, `COMMIT_LOCAL_THEMES=false`, or `PUSH_LOCAL_THEMES=false` when running the update script if you want to override that behavior.

---

## Activating a theme

**From Home Assistant:** The clock registers a `select` entity (`Theme`) on the device page. Pick any loaded theme from the dropdown. The selection takes effect immediately.

**Via MQTT:** Publish the theme name as a plain string or as a JSON object to the theme command topic:

```bash
# Plain string
mosquitto_pub -h <broker> -u <user> -P <pass> \
  -t hub75_clock/theme/set \
  -m 'Night'

# JSON object
mosquitto_pub -h <broker> -u <user> -P <pass> \
  -t hub75_clock/theme/set \
  -m '{"theme": "Night"}'
```

The clock publishes the active theme name to `hub75_clock/theme/state` (retained) so the HA select entity stays in sync.

**Available themes list:** `hub75_clock/themes/available` (retained JSON array) is updated automatically whenever files are added or removed from the themes directory.

---

## JSON schema

Every field except `name` is optional. Omitting a field uses the default.

### Identity

| Field | Type | Default | Description |
|---|---|---|---|
| `name` | string | **required** | Display name shown in Home Assistant and used as the theme identifier. Must be unique across all files in the themes folder. |
| `description` | string | `""` | Free-text note for your own reference. Not displayed anywhere by the clock. |

### Background

| Field | Type | Default | Description |
|---|---|---|---|
| `background_type` | string | `"solid"` | `"solid"` fills the animation zone with a single color. `"gradient"` blends between two colors with a split point. |
| `background_color` | hex string | `"#000820"` | Fill color when `background_type` is `"solid"`. |
| `background_top` | hex string | `"#0F0019"` | Top color when `background_type` is `"gradient"`. |
| `background_bottom` | hex string | `"#3C1400"` | Bottom color when `background_type` is `"gradient"`. |
| `background_split` | float 0.0–1.0 | `0.5` | Fraction of the animation zone height where the gradient transitions. `0.5` = halfway. `0.25` = upper quarter. |
| `background_gradient_direction` | string | `"sunset"` | `"sunrise"` or `"sunset"`. Controls which end is solid and which fades. See [Gradient direction](#gradient-direction) below. |

### Text colors

All values are hex color strings (`"#RRGGBB"`). When a key is present in the theme, it overrides the day/night color from `config.yaml` for that element.

| Field | Type | Default | Description |
|---|---|---|---|
| `colors.time` | hex string | from config | Large clock digits. |
| `colors.low_temp` | hex string | from config | Low temperature value in the banner. |
| `colors.high_temp` | hex string | from config | High temperature value in the banner. |
| `colors.condition` | hex string | from config | Weather condition word in the banner (e.g. `RAIN`, `CLEAR`). |

### Cameos

Animations are configured through the `cameos` array. One-shot cameos fire at a configurable rate. Persistent cameos, such as `stars` and `clouds`, start when the theme is applied and run every frame without a rate.

| Field | Type | Default | Description |
|---|---|---|---|
| `cameos` | array | `[]` | List of cameo objects. Each has `name` (string). One-shot cameos also use `chance_per_minute` (float). |

**Cameo object fields:**

| Field | Type | Description |
|---|---|---|
| `name` | string | Which animation to spawn. Python names come from `/etc/hub75-clock/animations/*.py`; C++ names come from compiled animations in `clock-cpp/src/animations/`. |
| `chance_per_minute` | float | Expected spawns per minute on average for one-shot cameos. Omit for persistent animations. |

Example:

```json
"cameos": [
  {"name": "stars"},
  {"name": "shooting_star", "chance_per_minute": 8},
  {"name": "ufo", "chance_per_minute": 2}
]
```

**Built-in animations** (installed to `/etc/hub75-clock/animations/` by `install.sh`):

| Name | Layer | Conditions | Themes | Description |
|---|---|---|---|---|
| `stars` | celestial | CLEAR, PARTLYCLOUDY | Night, Late Evening | **Persistent** - add without `chance_per_minute`. Twinkling star field rendered before the sun/moon layer. |
| `clouds` | foreground | _(any)_ | Day, Sunrise, Sunset, Late Evening | **Persistent** — add without `chance_per_minute`. Handles clouds AND all precipitation (rain, tstorm with lightning, snow, sleet). Driven by `cloud_density`, `cloud_speed`, `precipitation`, and `colors.cloud_day`. |
| `shooting_star` | celestial | CLEAR, PARTLYCLOUDY | Night, Late Evening | Fast diagonal streak with fading tail |
| `ufo` | foreground | CLEAR, PARTLYCLOUDY | Night, Late Evening | Saucer silhouette, cycling belly lights, occasional tractor beam abduction |
| `satellite` | celestial | CLEAR | Night | ISS-silhouette cross, diagonal slow pass |
| `meteor` | celestial | CLEAR | Night, Late Evening | Fast bidirectional diagonal with orange/red history trail |
| `comet` | celestial | CLEAR | Night | Slow diagonal with blue-white gradient tail |
| `airplane` | foreground | _(any)_ | Day, Sunrise, Sunset | Fuselage + wings + windows, mirrors to face direction of travel |
| `bird_flock` | foreground | _(any)_ | Day | V-formation of 5–7 birds with alternating flap frames |
| `butterfly` | foreground | CLEAR | Day | Open/closed wing frames, sine wave vertical drift, orange |
| `flutterflies` | foreground | CLEAR | Day | **Persistent** - add without `chance_per_minute`. Small pastel butterfly group with gentle wandering motion |
| `hot_air_balloon` | foreground | CLEAR, PARTLYCLOUDY | Day, Sunrise | 7×10px balloon with ROYGBIV stripes, drifts upward |
| `tumbleweed` | foreground | _(any)_ | Day | Rolling circle with rotation transform, slight bounce |
| `rainbow` | foreground | CLEAR, PARTLYCLOUDY | Day | ROYGBIV arc, 2px thick bands, fade in/hold/fade out |
| `firefly` | foreground | CLEAR | Night, Late Evening | 6–8 dots, independent sine-phase blink, slow drift, 2px tall |
| `snowman` | foreground | SNOW | _(any)_ | Pixel-art snowman, lower-right corner, fade in/out |
| `santa` | foreground | _(any)_ | Night, Late Evening | Sleigh + reindeer silhouette, right-to-left, sine altitude |
| `fireworks` | foreground | _(any)_ | _(any)_ | 1–3 physics-based rockets, 16–20 sparks each with velocity tails |
| `jack_o_lantern` | foreground | _(any)_ | Night, Late Evening | 9×7px pumpkin with triangle eyes and zigzag mouth, fade in/out |
| `easter_egg` | foreground | _(any)_ | Day | 6×8px striped oval, bounces left-to-right |
| `rocket` | foreground | _(any)_ | _(any)_ | 3×7px rocket, accelerates upward from random X, flame trail |
| `submarine` | foreground | _(any)_ | Day | Long hull + conning tower + periscope, slow left-to-right |
| `ghost` | foreground | _(any)_ | Night, Late Evening | Pac-Man ghost (Blinky/Pinky/Inky/Clyde colors), directional pupils, sine float |

The `layer` column shows when the animation is drawn relative to sun/moon and weather particles. `celestial` renders before sun/moon and clouds; `foreground` renders after clouds. See `docs/animations.md` for details.

See `docs/animations.md` for the drop-in animation interface and how to write your own.

### Clouds and precipitation

All clouds and precipitation are handled by the persistent `clouds` cameo animation. To enable clouds (with or without precipitation), add `{"name": "clouds"}` to the `cameos` array. Cloud count, size, speed, and particle type are controlled by the fields below.

| Field | Type | Default | Description |
|---|---|---|---|
| `cloud_density` | string | `"medium"` | Number of clouds. `"sparse"` = 2, `"medium"` = 4, `"dense"` = 7. |
| `cloud_speed` | string | `"medium"` | How fast clouds drift left. `"slow"` = 0.2 px/frame, `"medium"` = 0.4, `"fast"` = 0.7. |
| `precipitation` | string | `"none"` | Precipitation particles to emit below clouds. See table below. |
| `colors.cloud_day` | hex string | `"#646464"` | Cloud body color. Override per-theme for mood. |

**Precipitation modes:**

| Value | Effect |
|---|---|
| `"none"` | Clouds only, no particles. |
| `"rain"` | 2–4 blue rain streaks per cloud, 1.5 px/frame. |
| `"heavy_rain"` | 4–6 darker streaks per cloud, 2.5 px/frame. |
| `"tstorm"` | Heavy rain plus lightning bolts (8–15 s intervals) with a brief background flash. |
| `"snow"` | 2–3 white dots per cloud, 0.3–0.5 px/frame with gentle lateral wobble. |
| `"sleet"` | Mixed: half fast cyan-gray streaks, half slow wobbling dots. |

All particles are owned by the cloud that spawned them. They fall downward and wrap back to the cloud bottom when they exit the animation zone. When the cloud wraps around to the right edge, its particles are reset.

### Sun and Moon

| Field | Type | Default | Description |
|---|---|---|---|
| `sun_enabled` | bool | `true` | Draw the sun quarter-circle glow in the top-right corner when the condition is SUNNY and night mode is off. Set to `false` for themes where the background already represents the sun (e.g. sunrise gradient, sunset gradient), so the glow doesn't stack on top of the coloured sky. |
| `moon_enabled` | bool | `false` | Draw a small moon disk (radius 3, ~7×7px) in the upper-left corner of the animation zone with a mottled gray surface and a dim glow border. Intended for night and late-evening themes. |

### Condition overrides

| Field | Type | Default | Description |
|---|---|---|---|
| `condition_overrides` | object | `{}` | Per-condition background overrides. Keys are condition strings (see below). Values are objects containing any subset of the background fields (`background_type`, `background_color`, `background_top`, `background_bottom`, `background_split`, `background_gradient_direction`). Text colors, `cameos`, `sun_enabled`, and `moon_enabled` cannot be overridden per-condition. |

Example:

```json
"condition_overrides": {
  "TSTORM": {
    "background_type": "solid",
    "background_color": "#010005"
  },
  "RAIN": {
    "background_type": "gradient",
    "background_top": "#030010",
    "background_bottom": "#010008",
    "background_gradient_direction": "sunset"
  }
}
```

---

## Valid condition strings for overrides

```
CLEAR           SUNNY           PARTLYCLOUDY    CLOUDY
RAIN            SNOW            SLEET           TSTORM
ICE             FLOOD           BLIZZARD        HURRICANE
TROPICAL_STORM  FREEZING_RAIN   FREEZING_DRIZZLE
DUST            SMOKE
```

Aliased conditions (BLIZZARD→SNOW, HURRICANE→TSTORM, FLOOD→RAIN, etc.) are normalized before the override lookup, so use the canonical name, not the alias, as the key.

---

## Gradient direction

`background_gradient_direction` controls which portion of the animation zone is a solid fill and which fades.

```
sunrise:                    sunset:
┌──────────────┐            ┌──────────────┐
│  background  │            │  background  │  ← solid top
│     _top_    │  ← fades   │     _top_    │
│              │    down     │              │
├──────────────┤            ├──────────────┤  ← split point
│              │            │              │
│  background  │  ← solid   │  background  │  ← fades down
│   _bottom_   │   bottom   │   _bottom_   │
└──────────────┘            └──────────────┘
```

**Sunrise:** The top portion fades from `background_top` (at the very top) down to `background_bottom` (at the split). The bottom portion below the split is a solid fill of `background_bottom`. Good for dawn: dark purple sky above a warm horizon, flat dark ground below.

**Sunset:** The top portion above the split is a solid fill of `background_top`. The bottom portion fades from `background_top` (at the split) down to `background_bottom` (at the very bottom). Good for dusk. The sky holds its color and bleeds into a warm horizon at the bottom.

`background_split: 0.5` puts the transition at the vertical midpoint of the animation zone. Lower values (e.g. `0.25`) push it toward the top; higher values (e.g. `0.75`) push it toward the bottom.

---

## Installing a theme

1. Write your JSON file (see [example](#complete-example) below).
2. Copy it to the themes directory:
   ```bash
   sudo cp stormy_night.json /etc/hub75-clock/themes/
   ```
3. The clock detects the new file within a few seconds and adds it to the available themes list.
4. Select it from the HA device page or via MQTT.

No restart or C++ recompile is required for normal theme JSON edits. New C++ animation code or changes to compiled animation behavior still require `make update` on the C++ clock.

---

## Complete example

`stormy_night.json`: a dark, dramatic theme for thunderstorm nights with lightning.

```json
{
  "name": "Stormy Night",
  "description": "Dark stormy sky with lightning",

  "background_type": "solid",
  "background_color": "#010004",

  "colors": {
    "time":      "#383838",
    "low_temp":  "#001C2A",
    "high_temp": "#2A1100",
    "condition": "#141418",
    "cloud_day": "#1C1C24"
  },

  "cameos": [{"name": "clouds"}],

  "cloud_density": "dense",
  "cloud_speed": "fast",
  "precipitation": "tstorm",

  "sun_enabled": false,
  "moon_enabled": false
}
```

**Field-by-field notes:**

- `background_color: "#010004"`: near-black with a faint purple tint. Keeps the panel very dim.
- `colors.time: "#383838"`: dark grey — a bright clock face is intrusive at night.
- `colors.cloud_day: "#1C1C24"`: very dark clouds, barely visible — storm clouds blocking all light.
- `precipitation: "tstorm"`: heavy rain particles plus random lightning bolts with a brief background flash. Lightning interval is 8–15 seconds.
- `cloud_density: "dense"` + `cloud_speed: "fast"`: 7 fast-moving clouds feel stormy and oppressive.
- No `stars` cameo: no stars; total overcast.

---

## Tips

- **Keep colors dim for night themes.** Time and temperature colors in the `#303030`–`#606060` range are readable without lighting up a dark room. Use `#F0F0F0` only for daytime themes.

- **Condition overrides are the right place for weather-reactive backgrounds.** A day theme might have a bright blue sky by default but darken to near-black during TSTORM. That way you get one theme that adapts rather than needing separate themes for every combination of time-of-day and weather.

- **Theme names must be unique** across all `.json` files in the themes folder. If two files declare the same `name`, the second one loaded wins (load order is filesystem-alphabetical). Use a clear, descriptive name.

- **You can have as many themes as you want.** The HA select entity updates its options list automatically. There is no limit.

- **Drop a theme file in place to update it.** The watchdog detects the write and reloads. If the active theme was modified, it stays active with the new settings applied immediately.

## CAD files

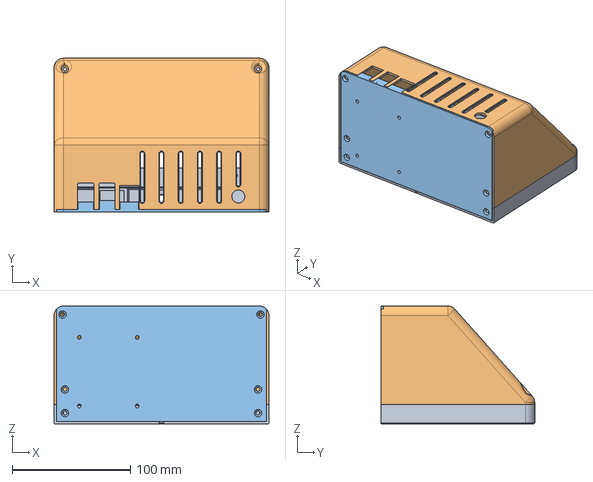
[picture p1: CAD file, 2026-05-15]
case/step files/Whole Assembly (pi4).step
181.9 x 129.9 x 99.8 mm

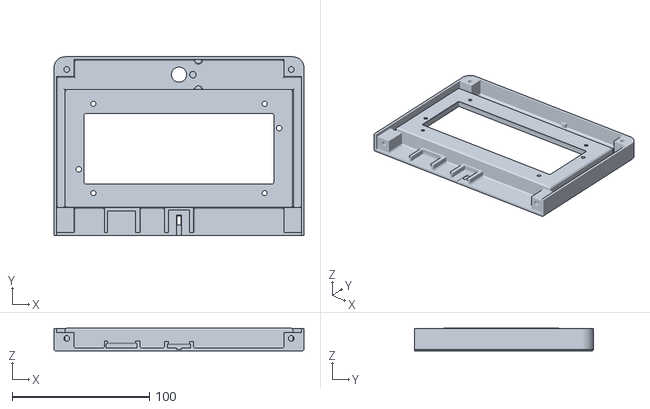
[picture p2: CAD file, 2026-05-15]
case/Front Cover (w VEML-PIR-MMWV).stl
181.9 x 129.9 x 16.5

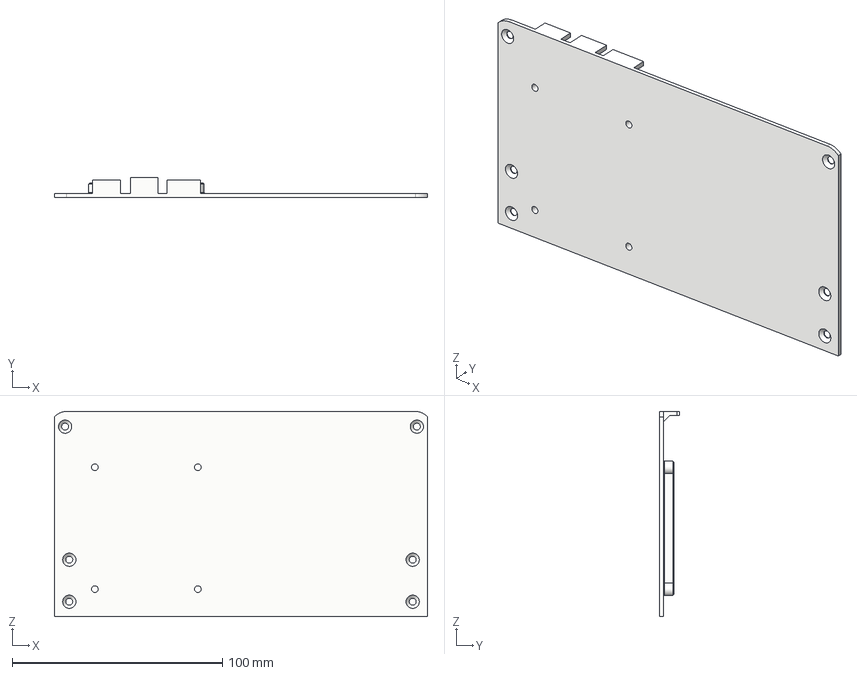
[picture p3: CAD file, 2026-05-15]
case/step files/Bottom Cover (pi4).step
177.5 x 9.45 x 97.6 mm

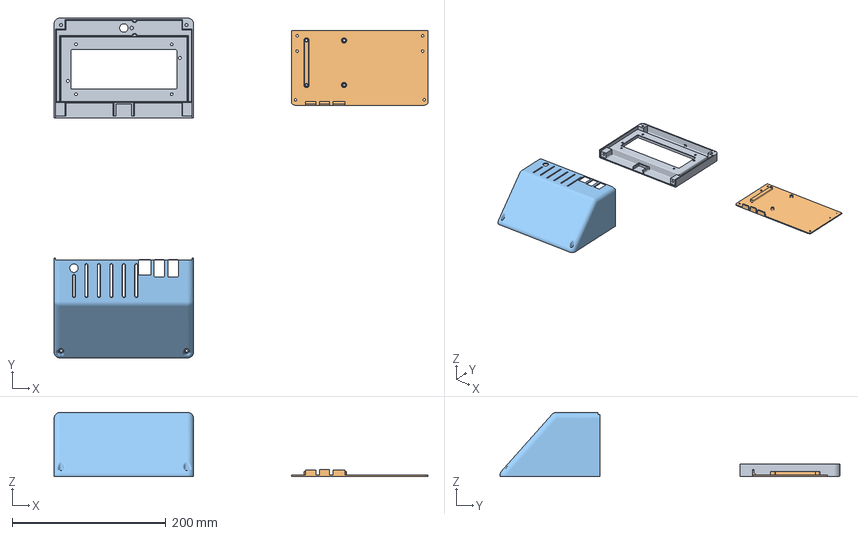
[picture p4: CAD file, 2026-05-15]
case/HUB-75 Clock (Pi4).3mf
486.9 x 442.6 x 83.5 mm
Front Cover no VEML.stl
Bottom Cover (pi4).stl
Back Cover (pi4 cutouts).stl

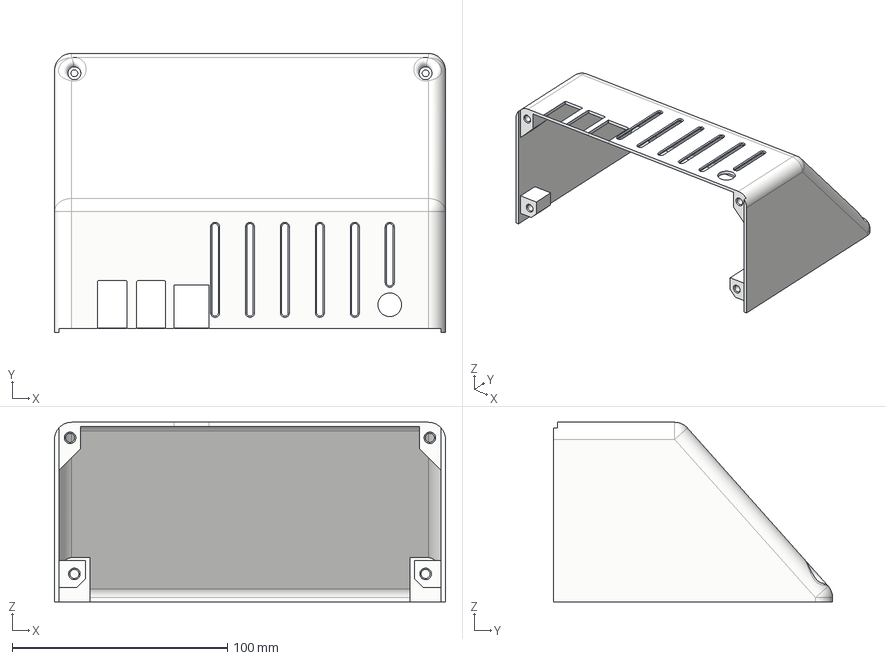
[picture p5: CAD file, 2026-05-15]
case/step files/Back Cover (pi4 cutouts).step
181.9 x 129.9 x 83.5 mm

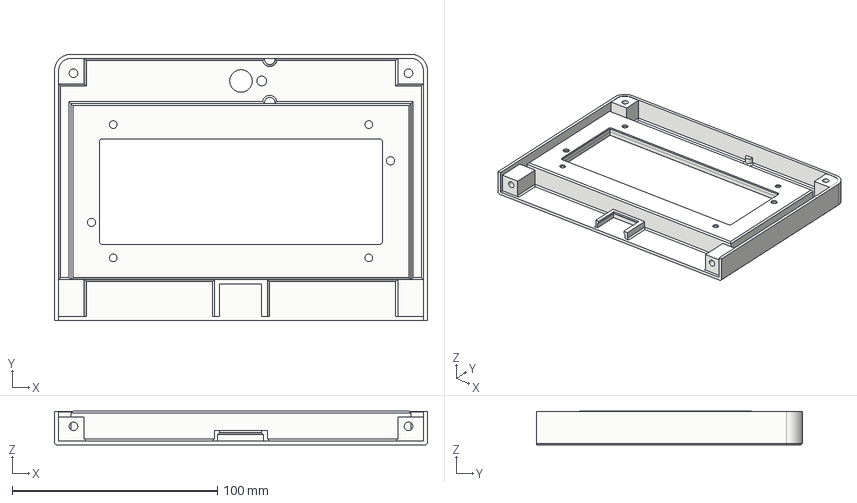
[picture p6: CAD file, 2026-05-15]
case/step files/Front Cover (no VEML).step
181.9 x 129.9 x 16.5 mm

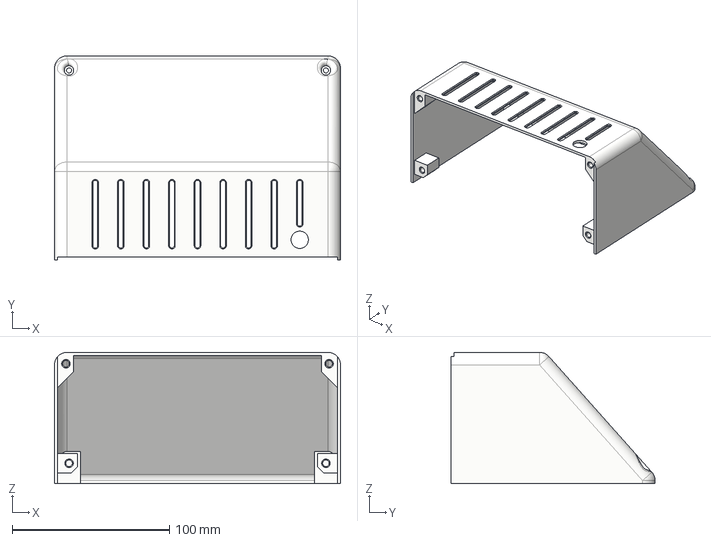
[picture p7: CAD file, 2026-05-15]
case/step files/Back Cover (only barrel jack).step
181.9 x 129.9 x 83.5 mm

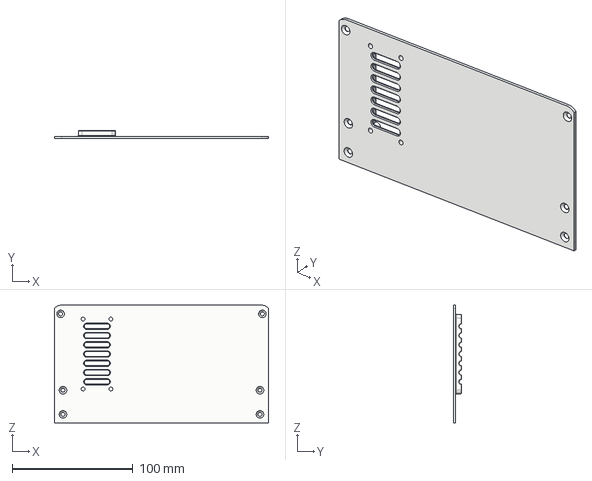
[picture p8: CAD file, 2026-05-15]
case/step files/Bottom Cover (piZero).step
177.5 x 6.80 x 97.6 mm

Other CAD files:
case/step files/Front Cover (all 3 sensors).step
case/Back Cover (only barrel jack).stl
case/Back Cover (pi4 cutouts).stl
case/Bottom Cover (pi4).stl
case/Bottom Cover (piZero).stl
case/Front Cover (no VEML).stl

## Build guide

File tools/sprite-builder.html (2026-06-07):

HUB75 Sprite Builder

ThemesSpriteCameo

New Save Save As

Sprite

Name

Width

Height

PrevFrame 1/1Next

AddDuplicateDelete

Frame Timems

Zoom25%

Resize Grid

Sprite frames describe visual states. Cameo movement decides where to put them.

Paint

Add Custom

AlphaFF

Draw Paint Eyedropper Erase

Used in this Sprite

Built in

Custom

ClearFill All

Paint uses 4-way fill only. Right click erases. Right click a custom color to remove it.

Cameo

Load

NewSaveSave As

Name

Speed

Move

Direction

Random start Random facing

Persistent

Fixed X

Fixed Y

Sprites

Stray

Spin

Spin Speed

Loop

PrevFrame 1/1Next

AddDuplicateDeletePlay

Durationms

Sprite

X

Y

Rotationdeg

Preset movement defines where sprites go. Custom frames give full manual frame-by-frame control.

Preview

Theme cameo example: {"name":"sprite","sprite":"rocket","chance_per_minute":4}

JSON

Apply JSONCopy

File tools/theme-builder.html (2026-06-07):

HUB75 Theme Builder

ThemesSpriteCameo

New Save Save As Load JSON Export JSON Copy JSON

Identity

Name

Description

Background

Type

Color

Top

Bottom

Split 0.50

Direction

Animations

Stars

Sun

Moon

Clouds

Density

Speed

Colors

Time

Low Temp

High Temp

Condition

Cameos

+ Add Cameo

Preview approximates the clock: colors, weather, stars, shooting stars, sun, moon, and clouds are represented; exact BDF font rendering and full cameo sprites are not.

Condition

Night

Low

High

Condition text

Animate

Legend

Editable JSON

Generated Apply JSON Copy

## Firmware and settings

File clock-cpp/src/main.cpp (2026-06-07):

#include "WeatherAnimator.h"
#include "Theme.h"
#include "Sensors.h"

#include <led-matrix.h>
#include <graphics.h>

#include <yaml-cpp/yaml.h>
#include <nlohmann/json.hpp>
#include <mosquitto.h>

#include <algorithm>
#include <array>
#include <atomic>
#include <cctype>
#include <cstdlib>
#include <cstdint>
#include <cstring>
#include <ctime>
#include <csignal>
#include <filesystem>
#include <fstream>
#include <iostream>
#include <mutex>
#include <stdexcept>
#include <string>
#include <thread>
#include <chrono>
#include <unordered_map>
#include <vector>

using namespace rgb_matrix;
using json = nlohmann::json;
namespace fs = std::filesystem;

static const std::vector<std::pair<std::string, std::string>>& animationDefaultBlocks() {
    static const std::vector<std::pair<std::string, std::string>> blocks = {
        {"rocket", "  speed: 0.25\n"},
        {"meteor", "  speed: 0.3\n"},
        {"hot_air_balloon", "  speed: 0.5\n"},
        {"santa", "  speed: 0.5\n"},
        {"tumbleweed", "  speed: 0.5\n"},
        {"fireworks", "  speed: 1.0\n"},
        {"flutterflies", "  speed: 1.0\n"},
        {"clouds",
         "  speed: 1.0\n"
         "  particle_speed: 1.0\n"
         "  rain_speed: 1.0\n"
         "  heavy_rain_speed: 1.0\n"
         "  snow_speed: 1.0\n"
         "  sleet_fast_speed: 1.0\n"
         "  sleet_slow_speed: 1.0\n"},
    };
    return blocks;
}

static void ensureAnimationSettingsDefaults(const std::string& path) {
    try {
        fs::path p(path);
        if (!p.parent_path().empty()) fs::create_directories(p.parent_path());

        if (!fs::exists(path)) {
            std::ofstream out(path);
            out << "# Per-animation speed multipliers.\n"
                << "# Added automatically; edit these values to tune runtime speed.\n";
            for (const auto& block : animationDefaultBlocks()) {
                out << "\n" << block.first << ":\n" << block.second;
            }
            std::cout << "[config] created " << path << "\n";
            return;
        }

        YAML::Node existing = YAML::LoadFile(path);
        if (!existing.IsMap()) return;

        std::vector<const std::pair<std::string, std::string>*> missing;
        for (const auto& block : animationDefaultBlocks()) {
            if (!existing[block.first]) missing.push_back(&block);
        }
        if (missing.empty()) return;

        std::ofstream out(path, std::ios::app);
        out << "\n# Added automatically for new animation defaults.\n";
        for (const auto* block : missing) {
            out << "\n" << block->first << ":\n" << block->second;
        }
        std::cout << "[config] added missing animation defaults to " << path << "\n";
    } catch (const std::exception& e) {
        std::cerr << "[config] Failed to update animation defaults: " << e.what() << "\n";
    }
}

// ── Defaults (mirror Python DEFAULTS dict) ────────────────────────────────────

static json defaults() {
    return {
        {"mqtt", {
            {"broker", ""},
            {"port", 1883},
            {"username", ""},
            {"password", ""},
            {"client_id", "hub75_clock"},
            {"topics", {
                {"weather",          "clock/weather"},
                {"config",           "clock/config"},
                {"alert",            "clock/alert"},
                {"lux",              "hub75_clock/lux"},
                {"presence",         "hub75_clock/presence"},
                {"motion",           "hub75_clock/motion"},
                {"pir",              "hub75_clock/pir"},
                {"availability",     "hub75_clock/status"},
                {"fonts_available",  "hub75_clock/fonts_available"},
                {"gates",            "hub75_clock/gates"},
                {"engineering_mode", "hub75_clock/engineering_mode"},
                {"bucket",           "hub75_clock/bucket"},
                {"theme",            "hub75_clock/theme/set"},
                {"theme_state",      "hub75_clock/theme/state"},
                {"themes_available", "hub75_clock/themes/available"},
                {"ld2410_params",    "hub75_clock/ld2410/params"},
                {"ld2410_read",      "hub75_clock/ld2410/read"},
            }},
        }},
        {"ha_discovery", {
            {"enabled",            true},
            {"prefix",             "homeassistant"},
            {"ha_discovery_name",  "HUB75 Clock"},
            {"ha_discovery_area",  ""},
        }},
        {"theme_builder", {
            {"mode", "off"},
            {"service_name", "hub75-theme-builder"},
            {"host", "0.0.0.0"},
            {"port", 8765},
            {"url", ""},
        }},
        {"ld2410_tuner", {
            {"mode", "off"},
            {"service_name", "hub75-ld2410-tuner"},
            {"host", "0.0.0.0"},
            {"port", 8766},
            {"url", ""},
        }},
        {"panel", {
            {"hardware_mapping",    "regular"},
            {"gpio_slowdown",       2},
            {"led_rgb_sequence",    "RBG"},
            {"pwm_bits",            11},
            {"pwm_lsb_nanoseconds", 130},
            {"brightness",          60},
        }},
        {"fonts", {
            {"fonts_dir",   "/home/pi/rpi-rgb-led-matrix/fonts"},
            {"banner_name", "4x6.bdf"},
            {"banner_w",    4},
            {"banner_h",    6},
            {"time_name",   "spleen-12x24.bdf"},
            {"time_w",      12},
            {"time_h",      24},
            {"alert_name",  "4x6.bdf"},
            {"alert_w",     4},
            {"alert_h",     6},
        }},
        {"colors", {
            {"time_day",        "#F0F0F0"},
            {"low_temp_day",    "#00CCFF"},
            {"high_temp_day",   "#FF8C00"},
            {"condition_day",   "#909090"},
            {"alert_text",      "#FFFFFF"},
            {"alert_bg",        "#CC0000"},
            {"cloud_day",       {70, 70, 70}},
            {"sun_day",         {220, 160, 30}},
            {"ice_day",         {80, 140, 160}},
            {"outline",         {0, 0, 0}},
            {"sky_day",         "#000820"},
        }},
        {"animation", {
            {"fps",                        90},
            {"rain_count",                 {5, 8}},
            {"snow_count",                 {6, 10}},
            {"sleet_count",                {6, 10}},
            {"tstorm_rain_count",          {5, 8}},
            {"tstorm_lightning_chance",    0.015},
            {"tstorm_lightning_duration",  2},
        }},
        {"alert", {
            {"scroll_speed", 1},
            {"scroll_gap",   8},
            {"flash",        false},
            {"flash_period", 10},
            {"fill_region",  true},
        }},
        {"sensors", {
            {"lux_interval",      10.0},
            {"pir_poll_interval",  0.1},
            {"veml7700_enabled",  true},
            {"ld2410_enabled",    true},
            {"ld2410_port",       "/dev/serial0"},
            {"ld2410_baud",       256000},
            {"pir_enabled",       true},
            {"pir_gpio",          6},
            {"pir_invert",        false},
        }},
        {"time_format", {
            {"use_24h",     false},
            {"blink_colon", false},
        }},
        {"themes", {
            {"themes_dir",    "/etc/hub75-clock/themes"},
            {"default_theme", "Day"},
        }},
        {"animations", {
            {"animations_dir", "/etc/hub75-clock/animations"},
            {"sprites_dir", "/etc/hub75-clock/sprites"},
            {"settings_path", "/etc/hub75-clock/animations.yaml"},
        }},
    };
}

// ── Config loader ─────────────────────────────────────────────────────────────

// Recursively merge overlay into base (overlay wins on conflicts).
static json deepMerge(const json& base, const json& overlay) {
    json out = base;
    for (auto it = overlay.begin(); it != overlay.end(); ++it) {
        if (out.contains(it.key()) && out[it.key()].is_object() && it.value().is_object()) {
            out[it.key()] = deepMerge(out[it.key()], it.value());
        } else {
            out[it.key()] = it.value();
        }
    }
    return out;
}

static json yamlToJson(const YAML::Node& node) {
    switch (node.Type()) {
        case YAML::NodeType::Map: {
            json obj = json::object();
            for (const auto& kv : node) obj[kv.first.as<std::string>()] = yamlToJson(kv.second);
            return obj;
        }
        case YAML::NodeType::Sequence: {
            json arr = json::array();
            for (const auto& v : node) arr.push_back(yamlToJson(v));
            return arr;
        }
        case YAML::NodeType::Scalar: {
            const std::string s = node.as<std::string>();
            // Try int, then double, then bool, then string.
            try { return node.as<int>(); }    catch (...) {}
            try { return node.as<double>(); } catch (...) {}
            try { return node.as<bool>(); }   catch (...) {}
            return s;
        }
        default: return nullptr;
    }
}

static json loadConfig(const std::string& path) {
    json cfg = defaults();
    if (!fs::exists(path)) {
        std::cerr << "[config] " << path << " not found — using defaults\n";
        cfg["animation"]["fps"] = std::max(1, cfg["animation"].value("fps", 90));
        return cfg;
    }
    try {
        YAML::Node y    = YAML::LoadFile(path);
        json       user = yamlToJson(y);
        cfg = deepMerge(cfg, user);
        std::cout << "[config] loaded " << path << "\n";
    } catch (const std::exception& e) {
        std::cerr << "[config] Failed to parse " << path << ": " << e.what() << "\n";
    }
    cfg["animation"]["fps"] = std::max(1, cfg["animation"].value("fps", 90));
    return cfg;
}

static std::uint64_t themeDirSignature(const std::string& themesDir) {
    std::uint64_t sig = 1469598103934665603ull;
    std::error_code ec;
    for (const auto& entry : fs::directory_iterator(themesDir, ec)) {
        if (entry.path().extension() != ".json") continue;
        auto stamp = fs::last_write_time(entry.path(), ec).time_since_epoch().count();
        if (ec) {
            ec.clear();
            continue;
        }
        auto size = fs::file_size(entry.path(), ec);
        if (ec) {
            ec.clear();
            size = 0;
        }
        std::string name = entry.path().filename().string();
        for (unsigned char ch : name) {
            sig ^= ch;
            sig *= 1099511628211ull;
        }
        sig ^= static_cast<std::uint64_t>(stamp);
        sig *= 1099511628211ull;
        sig ^= static_cast<std::uint64_t>(size);
        sig *= 1099511628211ull;
    }
    return sig;
}

// ── Signal handling ───────────────────────────────────────────────────────────

static std::atomic<bool> g_running{true};
static std::atomic<int>  g_fps{90};

static void onSignal(int) { g_running = false; }

// ── Clock state ───────────────────────────────────────────────────────────────

struct ClockState {
    std::string lowTemp       = "--";
    std::string highTemp      = "--";
    std::string condition     = "CLEAR";
    bool        mqttConnected = false;
    std::string bucket        = "Day";
    std::string alertMessage;
};

// ── Color helpers ─────────────────────────────────────────────────────────────

// Mirrors Python _col(key): checks theme.colors[key], then cfg["colors"][key+"_day"],
// then cfg["colors"][key]. The key passed in has no suffix (e.g. "time", "low_temp").
static rgb_matrix::Color resolveTextColor(
    const std::string& key,
    const WeatherAnimator& animator,
    const json& cfg)
{
    if (animator.currentTheme) {
        auto it = animator.currentTheme->colors.find(key);
        if (it != animator.currentTheme->colors.end()) {
            auto c = resolveColor(it->second);
            return rgb_matrix::Color(c[0], c[1], c[2]);
        }
    }
    const auto& colors = cfg["colors"];
    std::string dayKey = key + "_day";
    if (colors.contains(dayKey)) {
        auto c = resolveColor(parseColorValue(colors[dayKey]));
        return rgb_matrix::Color(c[0], c[1], c[2]);
    }
    if (colors.contains(key)) {
        auto c = resolveColor(parseColorValue(colors[key]));
        return rgb_matrix::Color(c[0], c[1], c[2]);
    }
    return rgb_matrix::Color(200, 200, 200);
}

// ── Condition display text ────────────────────────────────────────────────────

static std::string displayCondition(const std::string& cond) {
    static const std::unordered_map<std::string, std::string> MAP = {
        {"SUNNY",            "SUNNY"},
        {"CLEAR",            "CLEAR"},
        {"PARTLYCLOUDY",     "CLOUDY"},
        {"CLOUDY",           "CLOUDY"},
        {"FOG",              "CLOUDY"},
        {"RAIN",             "RAIN"},
        {"SNOW",             "SNOW"},
        {"SLEET",            "SLEET"},
        {"TSTORM",           "TSTORM"},
        {"ICE",              "ICE"},
        {"BLIZZARD",         "BLIZZARD"},
        {"HURRICANE",        "HURRCN"},
        {"TROPICAL_STORM",   "T-STORM"},
        {"FLOOD",            "FLOOD"},
        {"FREEZING_RAIN",    "FRZRAIN"},
        {"FREEZING_DRIZZLE", "FRZDRIZ"},
        {"DUST",             "DUSTY"},
        {"SMOKE",            "SMOKY"},
        {"WINDY",            "WINDY"},
    };
    auto it = MAP.find(cond);
    return (it != MAP.end()) ? it->second : cond;
}
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
int main(int argc, char* argv[]) {
    std::string configPath = "/etc/hub75-clock/config.yaml";
    if (argc > 1) configPath = argv[1];

    json cfg = loadConfig(configPath);

    // Load per-animation speed settings from a separate YAML file.
    {
        const std::string animPath = "/etc/hub75-clock/animations.yaml";
        ensureAnimationSettingsDefaults(animPath);
        if (fs::exists(animPath)) {
            try {
                YAML::Node ay = YAML::LoadFile(animPath);
                cfg["animation_settings"] = yamlToJson(ay);
                std::cout << "[config] loaded " << animPath << "\n";
            } catch (const std::exception& e) {
                std::cerr << "[config] Failed to parse " << animPath << ": " << e.what() << "\n";
                cfg["animation_settings"] = json::object();
            }
        } else {
            cfg["animation_settings"] = json::object();
        }
    }

    // ── Matrix init ───────────────────────────────────────────────────────
    RGBMatrix::Options opts;
    RuntimeOptions rtopts;
    opts.hardware_mapping    = "regular";
    opts.rows                = 32;
    opts.cols                = 64;
    opts.chain_length        = 1;
    opts.parallel            = 1;
    opts.brightness          = cfg["panel"].value("brightness", 60);
    opts.pwm_bits            = cfg["panel"].value("pwm_bits", 11);
    opts.pwm_lsb_nanoseconds = cfg["panel"].value("pwm_lsb_nanoseconds", 130);
    rtopts.gpio_slowdown     = cfg["panel"].value("gpio_slowdown", 2);
    std::string ledRgbSequence = cfg["panel"].value("led_rgb_sequence", std::string("RBG"));
    opts.led_rgb_sequence    = ledRgbSequence.c_str();
    rtopts.drop_privileges   = 0;

    auto* matrix = CreateMatrixFromOptions(opts, rtopts);
    if (!matrix) {
        std::cerr << "[init] Failed to create RGB matrix\n";
        return 1;
    }

    // ── Font loading ──────────────────────────────────────────────────────
    std::string fontsDir   = cfg["fonts"].value("fonts_dir",   "/home/pi/rpi-rgb-led-matrix/fonts");
    std::string bannerPath = fontsDir + "/" + cfg["fonts"].value("banner_name", "4x6.bdf");
    std::string timePath   = fontsDir + "/" + cfg["fonts"].value("time_name",   "spleen-12x24.bdf");

    rgb_matrix::Font fontBanner, fontTime;
    if (!fontBanner.LoadFont(bannerPath.c_str()))
        std::cerr << "[init] Failed to load banner font: " << bannerPath << "\n";
    if (!fontTime.LoadFont(timePath.c_str()))
        std::cerr << "[init] Failed to load time font: " << timePath << "\n";

    // ── Theme loader ──────────────────────────────────────────────────────
    std::string themesDir = cfg["themes"].value("themes_dir", "/etc/hub75-clock/themes");
    ThemeLoader themeLoader(themesDir);

    // ── Weather animator ──────────────────────────────────────────────────
    WeatherAnimator animator(matrix->width(), matrix->height(), cfg, matrix);
    ensureThemeBuilderStartupState(cfg);
    ensureLd2410TunerStartupState(cfg);

    std::string defaultTheme = cfg["themes"].value("default_theme", "Day");
    animator.setTheme(defaultTheme, themeLoader);
    animator.setCondition("CLEAR");

    // ── Clock display state ───────────────────────────────────────────────
    ClockState clockState;

    // ── MQTT ──────────────────────────────────────────────────────────────
    mosquitto_lib_init();
    std::mutex animMtx;
    MqttCtx mqttCtx{&animator, &themeLoader, &clockState, &cfg, &animMtx, matrix};

    std::string clientId = cfg["mqtt"].value("client_id", "hub75_clock");
    auto* mosq = mosquitto_new(clientId.c_str(), true, &mqttCtx);
    if (!mosq) {
        std::cerr << "[mqtt] failed to create client\n";
        delete matrix;
        mosquitto_lib_cleanup();
        return 1;
    }
    mosquitto_connect_callback_set(mosq, mqttOnConnect);
    mosquitto_message_callback_set(mosq, mqttOnMessage);

    auto& topics = cfg["mqtt"]["topics"];
    std::string availabilityTopic = topics.value("availability", "hub75_clock/status");
    mosquitto_will_set(mosq, availabilityTopic.c_str(), 7, "offline", 0, true);

    std::string broker = cfg["mqtt"].value("broker", "");
    int         port   = cfg["mqtt"].value("port", 1883);
    if (!broker.empty()) {
        mosquitto_connect_async(mosq, broker.c_str(), port, 60);
        mosquitto_loop_start(mosq);
    }

    // ── Sensors ───────────────────────────────────────────────────────────
    // Publish helper: mosquitto_publish is thread-safe with loop_start.
    auto sensorPub = [mosq](const std::string& t, const std::string& p, bool retain) {
        mosquitto_publish(mosq, nullptr, t.c_str(),
                          int(p.size()), p.c_str(), 0, retain ? 1 : 0);
    };

    auto& sc = cfg["sensors"];

    std::unique_ptr<VEML7700Sensor> veml;
    if (sc.value("veml7700_enabled", true)) {
        veml = std::make_unique<VEML7700Sensor>(
            sensorPub,
            topics.value("lux", "hub75_clock/lux"),
            sc.value("lux_interval", 10.0));
    }

    std::unique_ptr<PIRSensor> pir;
    if (sc.value("pir_enabled", true)) {
        pir = std::make_unique<PIRSensor>(
            sensorPub,
            topics.value("pir", "hub75_clock/pir"),
            sc.value("pir_gpio",          6),
            sc.value("pir_poll_interval", 0.1),
            sc.value("pir_invert",        false));
    }

    std::unique_ptr<LD2410Sensor> ld2410;
    if (sc.value("ld2410_enabled", true)) {
        ld2410 = std::make_unique<LD2410Sensor>(
            sensorPub,
            topics.value("presence", "hub75_clock/presence"),
            topics.value("motion",   "hub75_clock/motion"),
            sc.value("ld2410_port", std::string("/dev/serial0")),
            static_cast<unsigned>(sc.value("ld2410_baud", 256000)));
    }

    // Wire LD2410 into MQTT context so gate/engineering_mode handlers work.
    mqttCtx.ld2410 = ld2410.get();

    if (veml)   veml->start();
    if (pir)    pir->start();
    if (ld2410) ld2410->start();

    // ── Signal handlers ───────────────────────────────────────────────────
    std::signal(SIGINT,  onSignal);
    std::signal(SIGTERM, onSignal);

    // ── Render loop ───────────────────────────────────────────────────────
    auto* canvas = matrix->CreateFrameCanvas();
    g_fps.store(std::max(1, cfg["animation"].value("fps", 90)));
    auto lastThemeCheck = std::chrono::steady_clock::now();
    std::uint64_t lastThemeSig = themeDirSignature(themesDir);

    while (g_running) {
        auto t0      = std::chrono::steady_clock::now();
        auto frameUs = std::chrono::microseconds(1'000'000 / std::max(1, g_fps.load()));

        if (t0 - lastThemeCheck >= std::chrono::seconds(1)) {
            lastThemeCheck = t0;
            std::uint64_t sig = themeDirSignature(themesDir);
            if (sig != lastThemeSig) {
                lastThemeSig = sig;
                std::lock_guard<std::mutex> lk(animMtx);
                std::string activeTheme = animator.currentTheme
                    ? animator.currentTheme->name
                    : cfg["themes"].value("default_theme", "Day");
                themeLoader.loadAll();
                animator.setTheme(activeTheme, themeLoader);

                auto themeNames = themeLoader.availableThemes();
                std::string themeList = json(themeNames).dump();
                mosquitto_publish(mosq, nullptr,
                                  topics.value("themes_available", clientId + "/themes/available").c_str(),
                                  int(themeList.size()), themeList.c_str(), 0, 1);
                if (animator.currentTheme) {
                    std::string name = animator.currentTheme->name;
                    mosquitto_publish(mosq, nullptr,
                                      topics.value("theme_state", clientId + "/theme/state").c_str(),
                                      int(name.size()), name.c_str(), 0, 1);
                }
                publishHomeAssistantDiscovery(mosq, cfg, themeNames);
                std::cout << "[theme_loader] reloaded themes\n";
            }
        }

        canvas->Clear();
        {
            std::lock_guard<std::mutex> lk(animMtx);
            animator.update();
            animator.draw(canvas);
            drawBanner(canvas, clockState, animator, cfg, fontBanner);
            drawTime(canvas, animator, cfg, fontTime);
        }
        canvas = matrix->SwapOnVSync(canvas);

        auto elapsed = std::chrono::steady_clock::now() - t0;
        if (elapsed < frameUs) std::this_thread::sleep_for(frameUs - elapsed);
    }
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

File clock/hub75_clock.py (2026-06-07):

#!/usr/bin/env python3
"""
HUB75 Smart Clock
================================
Changes from v1:
  - Per-element colors (time, low temp, high temp, condition, alert)
  - Colors changeable live via MQTT, saved to config.yaml
  - Font switching via MQTT (triggers auto-restart)
  - On startup, publishes available font list to hub75_clock/fonts_available
  - Hex color support in config (#RRGGBB)
"""

import os
import sys
import time
import math
import json
import signal
import threading
import random
import re
import importlib.util
import subprocess
import queue
from datetime import datetime, timezone
from typing import List, Optional, Tuple

import yaml
from rgbmatrix import RGBMatrix, RGBMatrixOptions, graphics
import paho.mqtt.client as mqtt
from theme_loader import ThemeLoader, Theme


DEFAULT_ANIMATION_SETTINGS = {
    "rocket": {"speed": 0.25},
    "meteor": {"speed": 0.30},
    "hot_air_balloon": {"speed": 0.5},
    "santa": {"speed": 0.5},
    "tumbleweed": {"speed": 0.5},
    "fireworks": {"speed": 1.0},
    "flutterflies": {"speed": 1.0},
    "clouds": {
        "speed": 1.0,
        "particle_speed": 1.0,
        "rain_speed": 1.0,
        "heavy_rain_speed": 1.0,
        "snow_speed": 1.0,
        "sleet_fast_speed": 1.0,
        "sleet_slow_speed": 1.0,
    },
}


try:
    import board
    import adafruit_veml7700
    HAS_VEML7700 = True
except (ImportError, NotImplementedError) as e:
    HAS_VEML7700 = False
    print(f"[init] VEML7700 unavailable: {e}")

try:
    import serial
    HAS_LD2410 = True
except ImportError:
    HAS_LD2410 = False
    print("[init] pyserial not found - LD2410C disabled")

try:
    import RPi.GPIO as GPIO
    HAS_PIR = True
except (ImportError, RuntimeError) as e:
    HAS_PIR = False
    print(f"[init] RPi.GPIO unavailable: {e}")


# ============================================================================
# COLOR HELPERS
# ============================================================================

def hex_to_rgb(hex_str: str) -> Tuple[int, int, int]:
    """Convert #RRGGBB to (r, g, b). Falls back to white on error."""
    try:
        h = hex_str.lstrip('#')
        return tuple(int(h[i:i+2], 16) for i in (0, 2, 4))
    except Exception:
        return (240, 240, 240)

def rgb_to_hex(r: int, g: int, b: int) -> str:
    return f"#{r:02X}{g:02X}{b:02X}"

def parse_color(val) -> Tuple[int, int, int]:
    """Accept either '#RRGGBB' string or [r, g, b] list."""
    if isinstance(val, str):
        return hex_to_rgb(val)
    elif isinstance(val, (list, tuple)) and len(val) == 3:
        return tuple(int(x) for x in val)
    return (240, 240, 240)


# ============================================================================
# CONFIG + LAYOUT LOADER
# ============================================================================

DEFAULTS = {
    "mqtt": {
        "broker": "",
        "port": 1883,
        "username": "",
        "password": "",
        "client_id": "hub75_clock",
        "topics": {
            "weather":          "clock/weather",
            "config":           "clock/config",
            "alert":            "clock/alert",
            "lux":              "hub75_clock/lux",
            "presence":         "hub75_clock/presence",
            "motion":           "hub75_clock/motion",
            "pir":              "hub75_clock/pir",
            "availability":     "hub75_clock/status",
            "fonts_available":  "hub75_clock/fonts_available",
            "gates":            "hub75_clock/gates",
            "engineering_mode": "hub75_clock/engineering_mode",
            "bucket":           "hub75_clock/bucket",
            "theme":            "hub75_clock/theme/set",
            "theme_state":      "hub75_clock/theme/state",
            "themes_available": "hub75_clock/themes/available",
            "ld2410_params":    "hub75_clock/ld2410/params",
            "ld2410_read":      "hub75_clock/ld2410/read",
        },
    },
    "ha_discovery": {
        "enabled":            True,
        "prefix":             "homeassistant",
        "ha_discovery_name":  "HUB75 Clock",
        "ha_discovery_area":  "",
    },
    "theme_builder": {
        "mode": "off",
        "service_name": "hub75-theme-builder",
        "host": "0.0.0.0",
        "port": 8765,
        "url": "",
    },
    "ld2410_tuner": {
        "mode": "off",
        "service_name": "hub75-ld2410-tuner",
        "host": "0.0.0.0",
        "port": 8766,
        "url": "",
    },
    "panel": {
        "hardware_mapping":    "regular",
        "gpio_slowdown":       2,
        "led_rgb_sequence":    "RBG",
        "pwm_bits":            11,
        "pwm_lsb_nanoseconds": 130,
        "brightness":          60,
    },
    "fonts": {
        # Use filenames only - resolved against fonts_dir at runtime
        "fonts_dir":   "/home/pi/rpi-rgb-led-matrix/fonts",
        "banner_name": "4x6.bdf",
        "banner_w":    4,
        "banner_h":    6,
        "time_name":   "spleen-12x24.bdf",
        "time_w":      12,
        "time_h":      24,
        "alert_name":  "4x6.bdf",
        "alert_w":     4,
        "alert_h":     6,
    },
    "colors": {
        "time_day":        "#F0F0F0",
        "low_temp_day":    "#00CCFF",
        "high_temp_day":   "#FF8C00",
        "condition_day":   "#909090",
        "alert_text":      "#FFFFFF",
        "alert_bg":        "#CC0000",
        "cloud_day":       [70, 70, 70],
        "sun_day":         [220, 160, 30],
        "ice_day":         [80, 140, 160],
        "outline":         [0, 0, 0],
        "sky_day":         "#000820",
    },
    "animation": {
        "fps":                        90,
        "rain_count":                [5, 8],
        "snow_count":                [6, 10],
        "sleet_count":               [6, 10],
        "tstorm_rain_count":         [5, 8],
        "tstorm_lightning_chance":   0.015,
        "tstorm_lightning_duration": 2,
    },
    "alert": {
        "scroll_speed": 1,
        "scroll_gap":   8,
        "flash":        False,
        "flash_period": 10,
        "fill_region":  True,
    },
    "sensors": {
        "lux_interval":       10.0,
        "pir_poll_interval":   0.1,
        "veml7700_enabled":   True,
        "ld2410_enabled":     True,
        "ld2410_port":        "/dev/serial0",
        "ld2410_baud":        256000,
        "pir_enabled":        True,
        "pir_gpio":           6,
        "pir_invert":         False,
    },
    "time_format": {
        "use_24h":     False,
        "blink_colon": False,
    },
    "themes": {
        "themes_dir":    "/etc/hub75-clock/themes",
        "default_theme": "Day",
    },
    "animations": {
        "animations_dir": "/etc/hub75-clock/animations",
        "sprites_dir": "/etc/hub75-clock/sprites",
        "settings_path": "/etc/hub75-clock/animations.yaml",
    },
}
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

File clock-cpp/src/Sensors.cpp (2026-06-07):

// Sensors.cpp — Linux userspace sensor implementations.
#include "Sensors.h"

#include <algorithm>
#include <cerrno>
#include <cmath>
#include <cstdio>
#include <cstring>
#include <fstream>
#include <iostream>
#include <string>

// POSIX / Linux platform headers
#include <fcntl.h>
#include <unistd.h>
#include <sys/ioctl.h>

// I2C userspace API (libi2c-dev / linux-headers)
#include <linux/i2c-dev.h>
#include <linux/i2c.h>
#include <gpiod.h>

// Defined in Serial.cpp
int openSerialPort(const char* port, unsigned baud);

// which are needed for the non-POSIX 256000 baud rate.

// ═══════════════════════════════════════════════════════════════════════════
// VEML7700 lux sensor
// ═══════════════════════════════════════════════════════════════════════════

static constexpr int     VEML7700_ADDR    = 0x10;
static constexpr uint8_t VEML7700_REG_CFG = 0x00;
static constexpr uint8_t VEML7700_REG_ALS = 0x04;

VEML7700Sensor::VEML7700Sensor(SensorPublish pub,
                                const std::string& topic,
                                double intervalSec)
    : _pub(std::move(pub)), _topic(topic), _intervalSec(intervalSec)
{
    if (!_init())
        std::cerr << "[veml7700] sensor not available — skipping\n";
}

VEML7700Sensor::~VEML7700Sensor() { stop(); }

bool VEML7700Sensor::_init() {
    _fd = open("/dev/i2c-1", O_RDWR);
    if (_fd < 0) return false;

    // Write config register 0x00 = 0x0000: 1x gain, 100 ms IT, ALS enabled.
    uint8_t cfgbuf[3] = {VEML7700_REG_CFG, 0x00, 0x00};
    struct i2c_msg wmsg;
    wmsg.addr  = static_cast<__u16>(VEML7700_ADDR);
    wmsg.flags = 0;
    wmsg.len   = 3;
    wmsg.buf   = cfgbuf;
    struct i2c_rdwr_ioctl_data wrdwr;
    wrdwr.msgs  = &wmsg;
    wrdwr.nmsgs = 1;
    if (ioctl(_fd, I2C_RDWR, &wrdwr) < 0) {
        close(_fd);
        _fd = -1;
        return false;
    }

    usleep(200'000); // 200 ms sensor warmup
    std::cout << "[veml7700] initialized on /dev/i2c-1\n";
    return true;
}

void VEML7700Sensor::start() {
    if (_fd < 0) return;
    _running = true;
    _thread  = std::thread([this] { _run(); });
}

void VEML7700Sensor::stop() {
    _running = false;
    if (_thread.joinable()) _thread.join();
    if (_fd >= 0) { close(_fd); _fd = -1; }
}
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

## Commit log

2026-05-15 v1.0.0 - Initial Release
    [Back Cover (only barrel jack).step, Back Cover (only barrel jack).stl, Back Cover (pi4 cutouts).step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]
2026-05-15 fixed entity naming conventions
    [hub75_clock.py]
2026-05-15 Changed PIR ground pin in readme. Can't use one that's already used!
2026-05-15 Another GND pin conflict in readme fixed.
2026-05-16 Removed sun from themes it would be weird in. First fix for pi0 install.
    [hub75_clock.py, theme_loader.py]
2026-05-16 fixing entity names and more install script edits
    [hub75_clock.py]
2026-05-18 remove condition filtering from CameoManager, cameos controlled by theme only
2026-05-18 fix update.sh: sync branch, copy themes and animations on update
    [theme_loader.py]
2026-05-19 update sample automations for cameo system, theme script, dual clock support
2026-05-19 personal themes: bucket-condition matrix, updated select theme script
2026-05-20 add missing bucket-condition themes for Early Morning, Evening, Late Evening
2026-05-21 fix: remove clouds_enabled from Theme dataclass and away.json, cloud rendering driven by cameos
    [theme_loader.py]
2026-05-21 fix: remove clouds_enabled from Theme dataclass
    [theme_loader.py]
2026-05-21 couple more color changes for the clouds. added in falloff cap that can be changed.
2026-05-21 fix: move ShootingStarCameo to animations/shooting_star.py, fix constructor, add persistent to firefly
    [hub75_clock.py]
2026-05-22 Revert "feat: C++17 scaffold for clock-cpp port"
    This reverts commit ed94d55b79bdf977cf037170192c43ba65624e62.
    [Theme.h]
2026-05-22 fix: degree symbol UTF-8, high temp right-align pixel offset
    [main.cpp]
2026-05-22 refactor: remove nightMode, dynamic fps, brightness MQTT wired up
2026-05-22 feat: implement VEML7700, PIR, LD2410C sensors in C++
2026-05-23 feat: animation speed, spawn, and direction adjustments
    - airplane, bird_flock: randomize Y spawn position (shifted 3 rows lower)
    - butterfly: 3 simultaneous butterflies with random pastel colors and directions
    - fireworks: fps-normalized velocities via 15/fps scale factor
    - hot_air_balloon, santa, tumbleweed: 0.5x movement speed
    - rocket: 0.25x movement speed and acceleration
    - meteor: 0.30x movement speed
    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
2026-05-23 Harden animation runtime error handling
    [hub75_clock.py, theme_loader.py]
2026-05-24 Fix C++ PIR gpiochip open path
    [Sensors.cpp]
2026-05-24 Adjust C++ banner high temperature position
2026-05-24 Adjust Python banner high temperature position
